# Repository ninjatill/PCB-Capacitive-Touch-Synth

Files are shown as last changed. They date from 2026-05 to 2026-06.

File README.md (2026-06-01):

# PCB-Capacitive-Touch-Synth
A Raspberry Pi-based synthesizer with capacitive touch keys directly on a PCB.

## Licensing

### Hardware
All files in `/hardware` are licensed under:

CC BY-NC-SA 4.0

### Firmware
All files in `/firmware` are licensed under:

GPLv3

## Concept
The PCB-Capacitive-Touch-Synth started as a sub-component of a larger science fair project. For my daughter's next science fair project (5th grade), she chose to create Plasma Speakers as we saw on the Franzoli Electronics YouTube page. The plasma speakers are flyback transformers that create a high-voltage arc (which ionizes the air into plasma). The frequeny of the arc creates audio tones. On Franzoli's demonstration videos, he plays MIDI-style music with each speaker acting as a left or right channel/voice. That is the concept we want to re-create.

If we re-create the plasma speakers, then how do we make then into an interactive display for the fair? Well, what if we had 2 midi-controller keyboards hooked up to a host PC. The host PC would do the heavy lifting of audio generation and output to the plasma speakers. Each keyboard would play its notes through either the left or right channel respectively. That's the main idea: 2 keyboards, a host PC, and plasma speakers.

To source the midi keyboards, you could go to Amazon and pick up a 30$-70$ keyboard (higher-end small midi keyboards can run upwards of 200-500$). But, commercial MIDI controllers usually do not output sound directly, it requires a host PC; so its usefullness outside the fair display is limited. The size and scale of the keyboards should be small (to match the entire setup which is portable and compact for a 36"-48" display.) The speakers on Franzoli's demos are very industrial/scientific looking. I thought commercial keyboards would look out of place or be too expensive. So I had a concept of creating keyboards printed on PCBs using capacitive touch buttons. The keyboards would be build to our specific needs and we can build in many features because of the DIY nature.

I decided the best course of action was to have my daughter re-create Fanzoli's Easy-Flyback circuits. It will teach her basic electrical components, schematic creation and PCB layout and fabrication. I think that's a wealth of knowledge for a 10 year old (maybe 11 by the time this comes to fruition). I will handle creating the PCB Capacitive Touch Synthesizer. It is a large complex project and is difficult for my own skill set.

## Documentation

- [Design Notes](docs/design-notes.md)

## Concept to Schematic
As an electrical engineer, I have created PCBs for simple devices. A capacitive touch synthesizer is the largest project/PCB I will have created. So, to jumpstart the project, I consulted my new "friend", ChatGPT. ChatGPT was able to answer questions and make recommendations faster than I could search DigiKey/Mouser, review datasheets, and find the right combination of ICs. But to be clear, I was driving the design. I wanted specific features and ChatGPT helped me realize those features faster than I could alone.

I started with the following design critera
- The front of the keyboard should be as flat as possible both for aestectic and functional reasons.
  - Aesthetically, I don't want a lot of clutter on the front of the board.
  - Functionally, Children will be interacting with this. I don't want exposed chip leads or solder pads. I also don't want through hole components sticking up with sharp edges. If kids can touch it, they will.
- The keyboard should be as small as possible but still allowing for decent usability (key widths wide enough for easy touch, etc.)
  
From the design criteria, we landed with some of the following choices:
- We will use capacitive touch sensors for the piano keys. Capacitive touch reduces mechanical parts that need fabricated (via 3D printing). It's more touch-friendly than many momentary push buttons.
- We will keep all IC's on the back of the board. Only LEDs and a volume knob will protrude from the front.
- We will use only surface mount components (to eliminate protrusions through the board and maintain the flat asthetic.)
- We will 3D print a back cover that serves 2 purposes: 
  - It will cover the back circuitry to prevent tampering.
  - It will raise the PCB off the display surface by a comfortable distance (and tilt it forward a few degrees) to increase usability.

## Basic Functionality
- The synthesizer will funtion in two main modes: standalone and MIDI.
  - In standalone mode, the keyboard will generate its own sounds via speaker or headphones.
  - In MIDI mode, the keyboard will send MIDI commands to a host PC (this is the intended mode for the science fair.

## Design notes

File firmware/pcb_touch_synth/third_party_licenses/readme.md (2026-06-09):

# Third-party licenses

This firmware is released under the **GNU General Public License v3.0** (see
`LICENSE` in the repository root). It incorporates the following third-party
components, each with their own license terms. Both are compatible with GPL v3.

---

## FatFS — Generic FAT Filesystem Module

- **Author:** ChaN
- **Source:** http://elm-chan.org/fsw/ff/
- **License:** FatFS License (BSD 1-clause style) — see `fatfs/license.txt`
- **Used by:** `audio/sample_loader.cpp` (via no-OS-FatFS-SD-SPI-RPi-Pico wrapper)
- **GPL v3 compatibility:** Compatible — permissive, no copyleft conditions

---

## no-OS-FatFS-SD-SPI-RPi-Pico

- **Author:** Carl John Kugler III
- **Source:** https://github.com/carlk3/no-OS-FatFS-SD-SPI-RPi-Pico
- **License:** Apache License 2.0 — see `no-os-fatfs-sd-spi-rpi-pico/license.txt`
- **Used by:** `audio/sample_loader.cpp`, `board/hw_config.c`
- **GPL v3 compatibility:** Compatible — the FSF explicitly states Apache 2.0 is
  compatible with GPL v3. See https://www.gnu.org/licenses/license-compatibility.html

---

## Raspberry Pi Pico SDK

- **Author:** Raspberry Pi Ltd
- **Source:** https://github.com/raspberrypi/pico-sdk
- **License:** BSD 3-Clause — included with the SDK distribution
- **Used by:** All firmware files
- **GPL v3 compatibility:** Compatible — permissive BSD licence

---

*These notices satisfy the attribution requirements of the Apache 2.0 and
FatFS licenses. The combined firmware as a whole is distributed under GPL v3.*

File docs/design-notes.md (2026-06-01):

# Design Notes

This document captures the reasoning behind major design choices in the PCB Capacitive Touch Synth project. The goal is to explain not only what was built, but why certain tradeoffs were made.

## Project Goals

- Standalone capacitive-touch musical keyboard/synth
- USB MIDI support for host-connected use
- Local audio output through speaker and/or headphones
- Compact PCB-first physical design
- Reasonably hand-assemblable prototype
- Open hardware and firmware structure

## Major Design Decisions

### PCB as the Primary Interface

The touch pads, labels, speaker grille, and user-facing controls are built directly into the PCB.

**Reasoning:**

- Reduces mechanical complexity
- Makes the PCB part of the finished product
- Supports capacitive touch pads directly on the board
- Keeps the enclosure simpler

**Tradeoffs:**

- PCB layout becomes more constrained
- Front-side aesthetics matter
- Routing must avoid touch-sensitive areas

---

### RP2040 Microcontroller

The project uses the RP2040 as the main controller.

**Reasoning:**

- Good GPIO count
- Strong USB support
- Low cost
- Good community/toolchain support
- PIO flexibility for future audio or protocol needs

**Tradeoffs:**

- No built-in DAC
- External flash required
- Some audio features require careful firmware design

---

### Capacitive Touch Input

Capacitive touch controllers are used instead of mechanical keys.

**Reasoning:**

- Keeps the top surface flat
- Reduces mechanical wear
- Supports a PCB-as-instrument design
- Allows flexible pad shapes and labels

**Tradeoffs:**

- Requires careful grounding and routing
- More sensitive to layout and environmental noise
- Firmware must handle calibration and false touches

---

### Local Audio Output

The board supports local audio through a small speaker and headphone output.

**Reasoning:**

- Allows standalone operation without a host computer
- Makes the instrument immediately usable
- Supports testing without external equipment

**Tradeoffs:**

- Audio layout requires more care
- Speaker volume and bass are limited by enclosure size
- Headphone/speaker switching adds schematic and layout complexity

---

### Separate Audio/Analog Ground Area

The audio section uses a more deliberate ground layout to reduce noise coupling.

**Reasoning:**

- Keeps noisy digital return currents away from sensitive audio paths
- Helps headphone and amplifier performance
- Makes the audio section easier to reason about during layout review

**Tradeoffs:**

- Ground regions must reconnect intentionally
- Poor stitching could make noise worse instead of better
- Requires review before fabrication

---

### GitHub Project Structure

The repository separates hardware and firmware.

```text
hardware/
firmware/
docs/
```

**Reasoning:**

- Keeps KiCad files separate from source code
- Allows hardware and firmware to evolve together
- Makes the project easier for others to navigate

**Tradeoffs:**

- Requires discipline around commits and documentation
- Generated fabrication outputs should be managed carefully

### Open Questions
- Final enclosure design
- Speaker chamber geometry
- Final firmware architecture
- USB MIDI/sample-transfer behavior
- Production versus prototype assembly choices

Revision Log
Date	Note
2026-05-19	Initial design notes document created

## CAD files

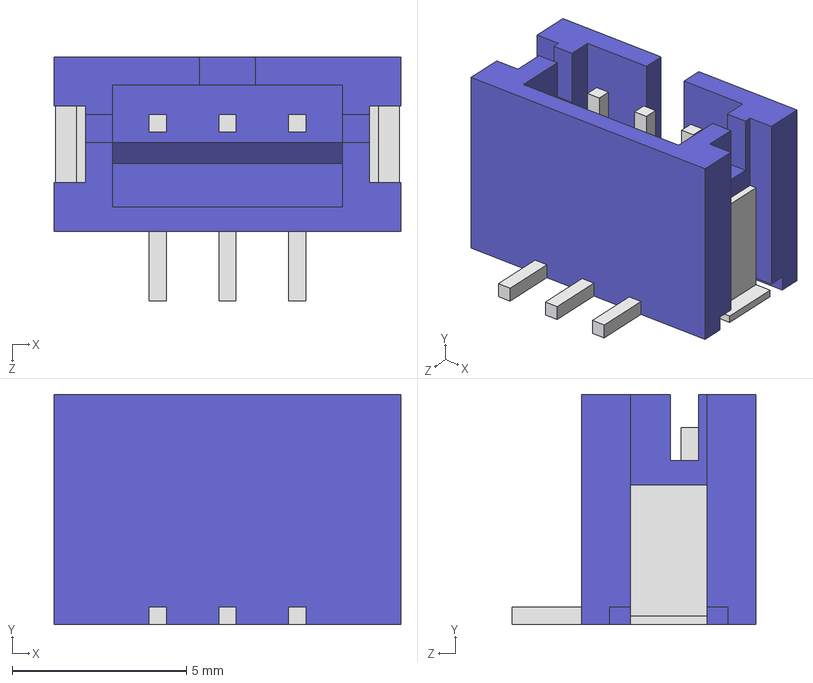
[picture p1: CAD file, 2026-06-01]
hardware/3dmodels/B3B-PH-SM4-TB.STEP
9.95 x 6.60 x 7.00 mm

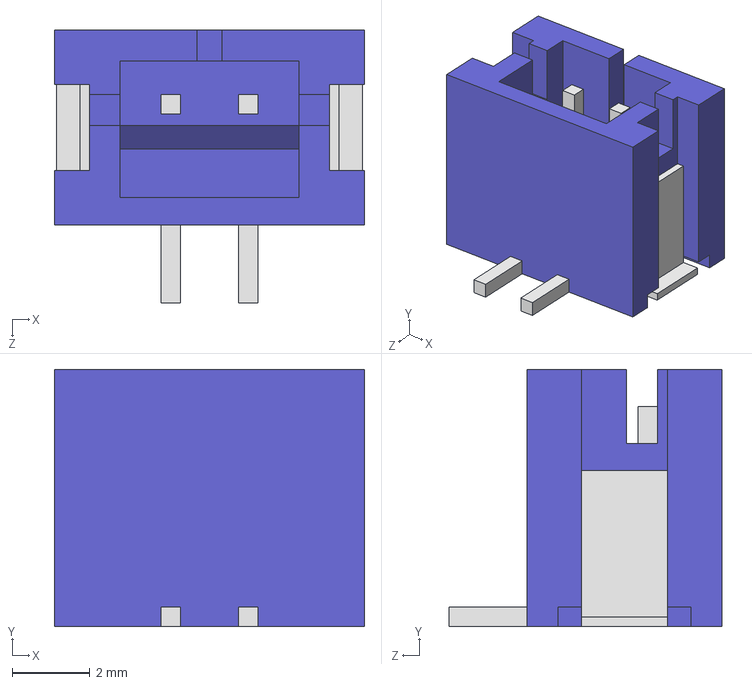
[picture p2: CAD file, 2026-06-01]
hardware/3dmodels/B2B-PH-SM4-TB.STEP
7.95 x 6.60 x 7.00 mm

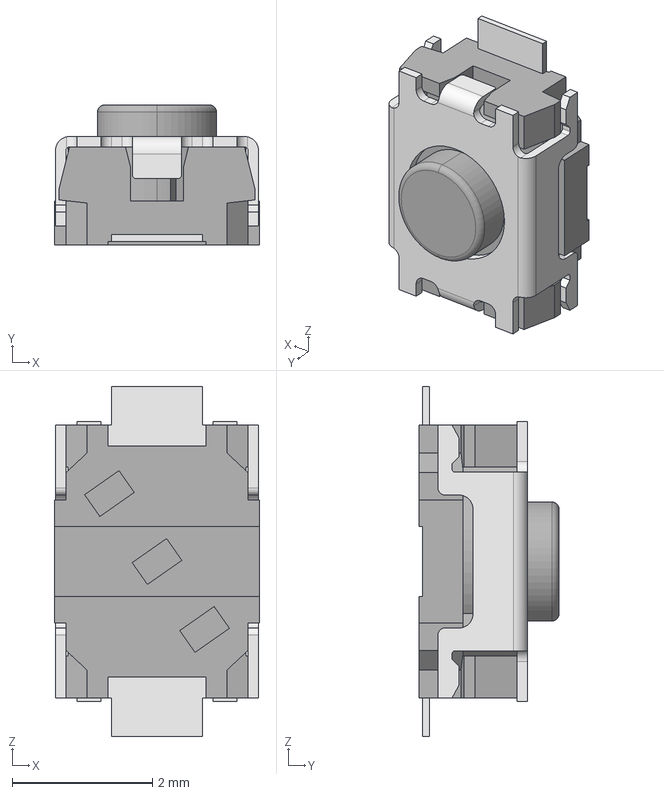
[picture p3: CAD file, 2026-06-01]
hardware/3dmodels/swt0110-020016ssa.stp
2.93 x 2.00 x 5.00 mm

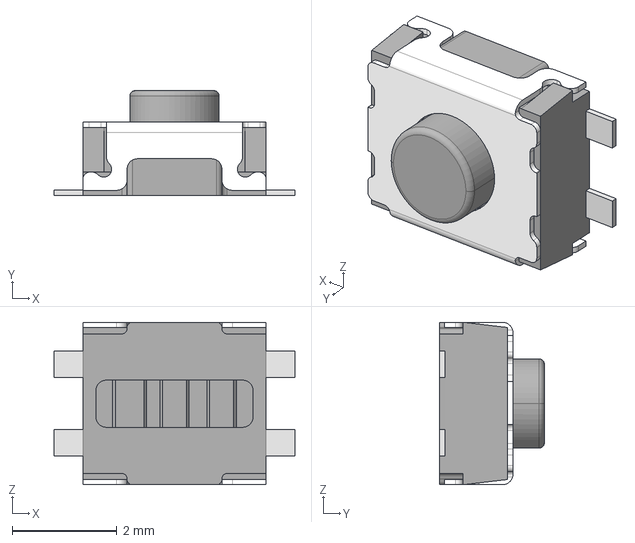
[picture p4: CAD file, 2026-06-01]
hardware/3dmodels/swt0115-020025ssa.stp
4.60 x 2.00 x 3.10 mm

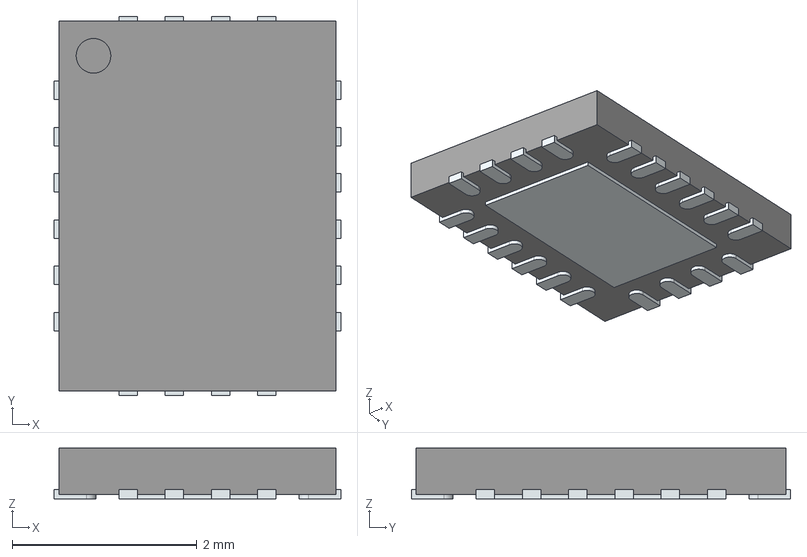
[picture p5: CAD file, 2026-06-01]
hardware/3dmodels/PI3USB9281CXWEX.stp
3.10 x 4.10 x 0.55 mm
ThermalPin
PinsArrayLR
PinsArrayTB

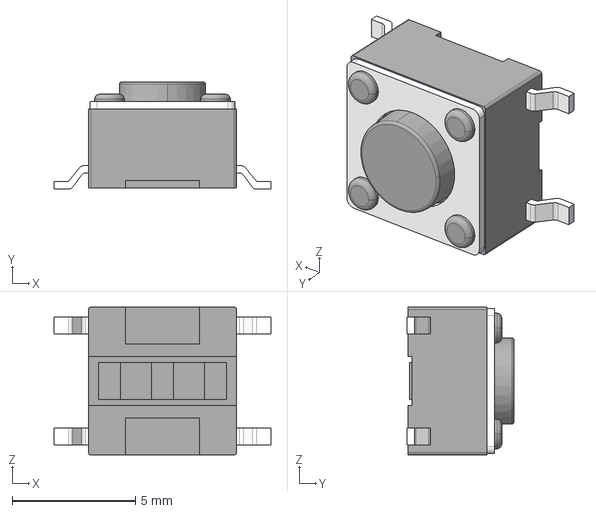
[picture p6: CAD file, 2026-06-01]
hardware/3dmodels/swt0310-043025gsa.stp
8.80 x 4.35 x 6.00 mm

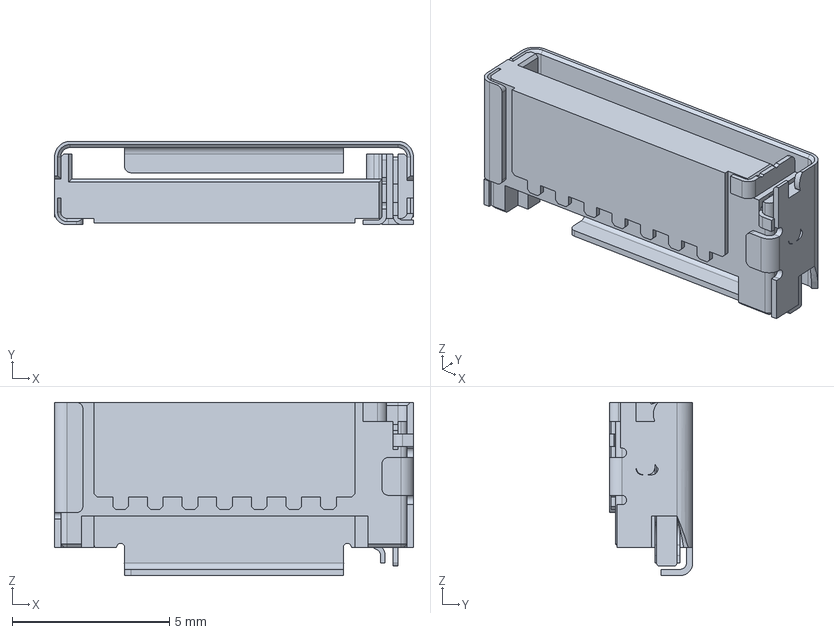
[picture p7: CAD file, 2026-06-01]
hardware/3dmodels/10067099-200lf.stp
11.4 x 2.65 x 5.50 mm

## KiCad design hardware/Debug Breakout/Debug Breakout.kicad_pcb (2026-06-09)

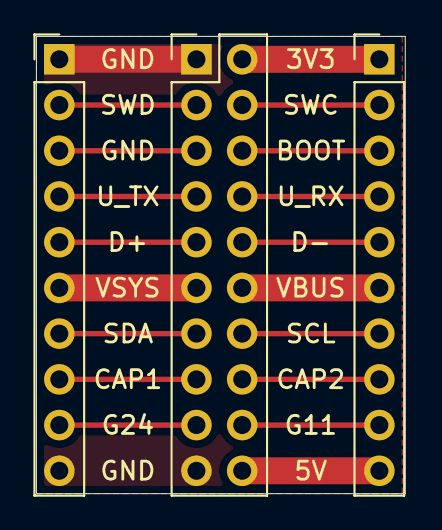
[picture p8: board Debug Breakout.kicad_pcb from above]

Board: 2 copper layers, 20.5 x 25.4 mm, 3 parts (0 on the bottom side), 19 nets.

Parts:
J1: PinHeader_2x10_P2.54mm_Vertical
J2, J3: Conn_01x10; PinHeader_1x10_P2.54mm_Vertical

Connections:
+3.3V: J1.2, J2.1
+5V: J1.20, J2.10
/BOOTSEL: J1.6, J2.3
/CAP1_GPIO: J1.15, J3.8
/CAP2_GPIO: J1.16, J2.8
/DEBUG_DM: J1.10, J2.5
/DEBUG_DP: J1.9, J3.5
/GPIO11: J1.18, J2.9
/GPIO24: J1.17, J3.9
/I2C1_SCL: J1.14, J2.7
/I2C1_SDA: J1.13, J3.7
/RUN: J1.5, J3.3
/SWCKL: J1.4, J2.2
/SWDIO: J1.3, J3.2
/UART1_RX: J1.8, J2.4
/UART1_TX: J1.7, J3.4
GND: J1.1, J1.19, J3.1, J3.10
VBUS: J1.12, J2.6
VSYS: J1.11, J3.6

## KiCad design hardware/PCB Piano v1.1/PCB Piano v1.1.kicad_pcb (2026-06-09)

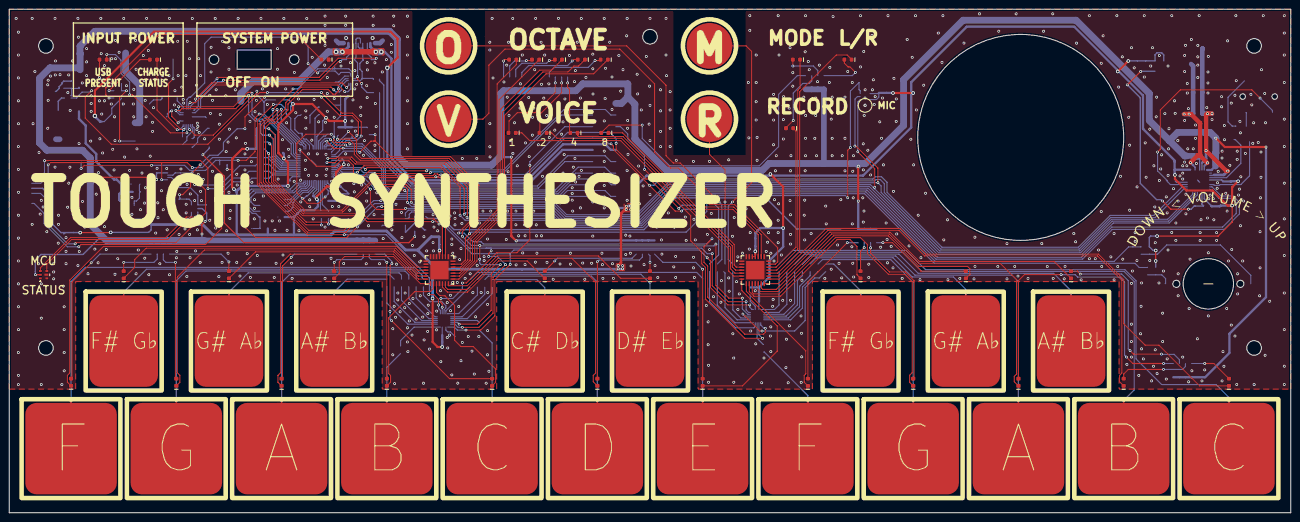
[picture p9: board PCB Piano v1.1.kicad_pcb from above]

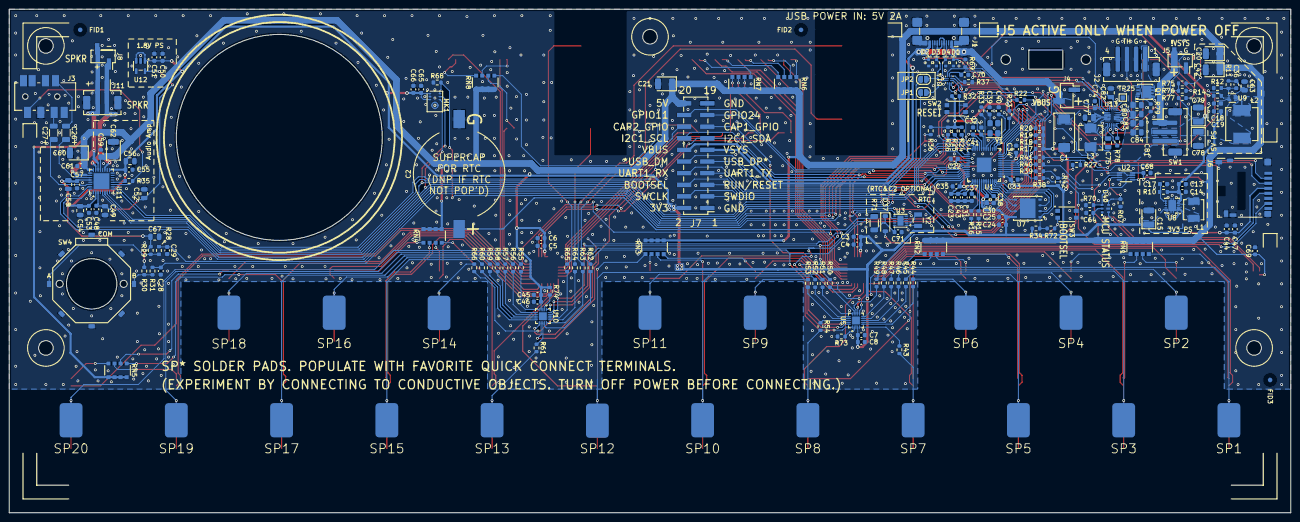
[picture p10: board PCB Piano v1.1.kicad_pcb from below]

Board: 2 copper layers, 280.0 x 110.0 mm, 284 parts (216 on the bottom side), 222 nets.

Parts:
C1: 47uF; CP_EIA-7343-43_Kemet-X
C2: 1F; SuperCap_HType_FoldedOutLegs
C3, C6, C8, C13, C18, C23, C24, C31, C37, C44, C45, C50, C66, C74: 1uF; C_0603_1608Metric
C4, C5, C7, C14, C17, C19, C22, C25, C28, C29, C30, C32, C33, C34, C35, C38, C41, C43, C46, C47, C48, C51, C53, C55, C57, C59, C61, C64, C65, C68, C69, C70, C71: .1uF; C_0603_1608Metric
C15, C20, C21, C42, C60, C62, C78, C79: 47uF; CP_EIA-3528-15_AVX-H
C26, C27: 100uF; C_1206_3216Metric
C36: 220pF; C_0603_1608Metric
C39, C40: 27pF; C_0603_1608Metric
C49, C52, C54, C56, C58, C63, C67, C77, C80, C81, C82, C83, C84: 10uF; C_0805_2012Metric
C75: 22nF; C_0805_2012Metric
D1, D2, D3, D4: ESD321; D_SOD-523
D5, D6, D7, D8, D9, D10, D11, D12, D13, D14, D15, D16, D17, D18, D19, D20, D21, D22, D23, D24, D25, D26, D27, D28, D29, D30, D31, D32, D33, D34, D35, D36, D43, D44, D45: 3.3fV 180mcd; LED_0603_1608Metric
D37: Schottky; D_SOD-123
D40, D41: Dotstar LED; APA102-2020
FID1, FID2, FID3: Fiducial; Fiducial_1mm_Mask3mm
H1, H2, H3, H4, H5: MountingHole; MountingHole_3.2mm_M3
J1: USB4110-GF-A; USB_C_Receptacle_GCT_USB4110
J2: JST PH 4-PIN; JST_PH_B4B-PH-SM4-TB_1x04-1MP_P2.00mm_Vertical
J3: 3.5mm TRRS; AudioJack_TRS_Switch_TR1R2S_SJ3-35024K-SMT-TR
J4, J5, J8: PinHeader 1x02 SMT; PinHeader_1x02_P2.54mm_Vertical_SMD_Pin1Right
J6: micro SD Card Slot; microSD_HC_Hirose_DM3D-SF
J7: PinHeader 2x10 SMT Odd_Even; PinHeader_2x10_P2.54mm_Vertical_SMD
J11: JST-PH 2-PIN SMT; JST_PH_B2B-PH-SM4-TB_1x02-1MP_P2.00mm_Vertical
JP1, JP2: SolderJumper_2_Open; SolderJumper-2_P1.3mm_Open_RoundedPad1.0x1.5mm
L1: 2.2uH; L_Bourns_SRP4020T_4.06x4.45x2.0mm
L2: 2.2uH; L_Pulse_BMRB00060630_7.3x6.6mm
L3: 1uH; L_Sumida_0530CDMCCDS-1R0MC_5.4x5.2mm
MK1: MEMS I2S Microphone; InvenSense_ICS-43432-7_4x3mm
Q1: P-Ch Power MOSFET; PPAK_3x3
R10: 100; R_0603_1608Metric
R11: 732k; R_0603_1608Metric
R12, R14, R25, R26, R27, R36, R37, R67, R69, R70, R73, R74, R79: 100k; R_0603_1608Metric
R15, R16, R38, R39, R40, R41: 27; R_0603_1608Metric
R17, R18, R19, R20: 4.7k; R_0603_1608Metric
R22, R23, R24, R28, R29, R30, R31, R32, R34, R42, R43, R44, R45, R46, R47, R48, R49, R50, R51, R52, R53, R54, R55, R56, R57, R58, R59, R60, R61, R62, R63, R64, R65, R66, R68, R78: 10k; R_0603_1608Metric
R33, R72: 1k; R_0603_1608Metric
R35: 2.2k; R_0603_1608Metric
R71: 150; R_1206_3216Metric
R75, R76, R77: 1.5k; R_0603_1608Metric
RN1, RN2, RN3, RN4, RN5, RN6, RN7, RN8: 180 Ohm; R_Array_Convex_4x1206
SP1, SP2, SP3, SP4, SP5, SP6, SP7, SP8, SP9, SP10, SP11, SP12, SP13, SP14, SP15, SP16, SP17, SP18, SP19, SP20: Pad_Solder_SMT_5x7mm
SW1: JST-PH 1x03 SMT; JST_PH_B3B-PH-SM4-TB_1x03-1MP_P2.00mm_Vertical
SW2, SW3: Pushbutton MO; SW_SWT0115-020025SSA_REVA
SW4: MER1045-24; Switch_RotaryEncoder_MER1045-24
SWCUT1: MFS 126 D; Switch_Slide_MFS126E_PanelCutout
TP1, TP3, TP5, TP7, TP8, TP10, TP12, TP13, TP15, TP17, TP19, TP20: Touchpad_WhiteKey
TP2, TP4, TP6, TP9, TP11, TP14, TP16, TP18: Touchpad_BlackKey
TP21, TP22, TP23, TP24: Touchpad_Circle_10mm
TP25: TestPoint_Square; TestPoint_Pad_1.0x1.0mm
U1: RP2040; QFN-56-1EP_7x7mm_P0.4mm_EP3.2x3.2mm
U2: Dual Line Buffer; VSSOP-8_2.3x2mm_P0.5mm
U3: RTC; DFN-10-1EP_2.6x2.6mm_P0.5mm_EP1.3x2.2mm
U4, U6: LED Controller; NXP_HVQFN-28_6mmx6mmx0.85mm
U5, U10: Touch Controller; VQFN-20-1EP_3x3mm_P0.4mm_EP1.7x1.7mm
U7: 128MBit; WSON-8-1EP_6x5mm_P1.27mm_EP3.4x4.3mm
U8: 3.3V; Texas_DRC0010J
U9: 5V; SOT-563
U11: Audio DAC Class-D I2S/I2C; Texas_RHB0032E_VQFN-32-1EP_5x5mm_P0.5mm_EP3.45x3.45mm
U12: 1.8V; SOT-23-5
U13: USB C Sink Ctrl/Batt Chgr; QFN-22_2.5x3.2mm_P0.4mm
U14: 1:2 USB MUX; TQFN-10_ZL_1.6x1.3mm_P0.4mm
Y1: 12MHz; Crystal_SMD_Abracon_ABM8G-4Pin_3.2x2.5mm
Y2: 32.768kHz; Crystal_Kyocera_DT32_3.2x1.5mm

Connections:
+1V1: C37.1, C38.1, C41.1, U1.23 (DVDD), U1.45 (VREG_VOUT), U1.50 (DVDD)
+1V8: C48.1, C49.1, C52.1, U11.3 (DVDD), U12.5 (OUT)
+3.3V: C3.1, C4.1, C5.1, C6.1, C7.1, C8.1, C15.1, C22.1, C23.1, C24.1, C25.1, C30.1, C31.1, C32.1, C33.1, C34.1, C35.1, C43.1, C44.1, C45.1, C46.1, C47.1, C50.1, C51.1, C53.1, C54.1, C55.1, C56.1, C57.1, C58.1, C65.1, C66.1, C67.1, J6.4 (VDD), J7.2, MK1.1 (LR), MK1.3 (VDD), R17.1, R18.1, R19.1, R20.1, R22.1, R23.1, R24.1, R25.1, R26.1, R27.1, R29.2, R30.2, R32.1, R34.1, R36.1, R42.1, R74.1, U1.1 (IOVDD), U1.10 (IOVDD), U1.22 (IOVDD), U1.33 (IOVDD), U1.42 (IOVDD), U1.43 (ADC_AVDD), U1.44 (VREG_VIN), U1.48 (USB_VDD), U1.49 (IOVDD), U4.25 (VDD), U5.4 (VDD), U6.25 (VDD), U6.26 (A0), U7.8 (VCC), U8.1 (VOUT), U8.10 (FB), U10.4 (VDD), U11.2 (IOVDD), U11.17 (AVDD), U11.28 (HPVDD), U12.1 (IN), U12.3 (EN)
+5V: C20.1, C21.1, C36.1, C42.1, C59.1, C60.1, C61.1, C62.1, C63.1, C64.1, C68.1, C69.1, D40.2 (VDD), D41.2 (VDD), J7.20, R11.1, RN1.5 (R4.2), RN1.6 (R3.2), RN1.7 (R2.2), RN1.8 (R1.2), RN2.5 (R4.2), RN2.6 (R3.2), RN2.7 (R2.2), RN2.8 (R1.2), RN3.5 (R4.2), RN3.6 (R3.2), RN3.7 (R2.2), RN3.8 (R1.2), RN4.5 (R4.2), RN4.6 (R3.2), RN4.7 (R2.2), RN4.8 (R1.2), RN5.5 (R4.2), RN5.6 (R3.2), RN5.7 (R2.2), RN5.8 (R1.2), RN6.5 (R4.2), RN6.6 (R3.2), RN6.7 (R2.2), RN6.8 (R1.2), RN7.5 (R4.2), RN7.6 (R3.2), RN7.7 (R2.2), RN7.8 (R1.2), RN8.5 (R4.2), RN8.6 (R3.2), RN8.7 (R2.2), RN8.8 (R1.2), U2.8 (VCC), U9.6 (VOUT), U11.21 (SPKVDD), U11.24 (SPKVDD)
/LED/I2C1_SCL: J7.14, R20.2, U1.9 (GPIO7), U3.7 (SCL), U4.23 (SCL), U6.23 (SCL), U11.10 (SCL), U13.16 (SCL)
/LED/I2C1_SDA: J7.13, R19.2, U1.8 (GPIO6), U3.6 (SDA), U4.24 (SDA), U6.24 (SDA), U11.9 (SDA), U13.15 (SDA)
/LED/LED_100: D5.1 (K), U4.3 (LED0)
/LED/LED_101: D6.1 (K), U4.4 (LED1)
/LED/LED_102: D7.1 (K), U4.5 (LED2)
/LED/LED_103: D8.1 (K), U4.6 (LED3)
/LED/LED_104: D9.1 (K), U4.7 (LED4)
/LED/LED_105: D10.1 (K), U4.8 (LED5)
/LED/LED_106: D11.1 (K), U4.9 (LED6)
/LED/LED_107: D12.1 (K), U4.10 (LED7)
/LED/LED_108: D13.1 (K), U4.12 (LED8)
/LED/LED_109: D14.1 (K), U4.13 (LED9)
/LED/LED_110: D15.1 (K), U4.14 (LED10)
/LED/LED_111: D29.1 (K), U4.15 (LED11)
/LED/LED_112: D28.1 (K), U4.16 (LED12)
/LED/LED_113: D27.1 (K), U4.17 (LED13)
/LED/LED_114: D26.1 (K), U4.18 (LED14)
/LED/LED_115: D25.1 (K), U4.19 (LED15)
/LED/LED_200: D30.1 (K), U6.3 (LED0)
/LED/LED_201: D31.1 (K), U6.4 (LED1)
/LED/LED_202: D32.1 (K), U6.5 (LED2)
/LED/LED_203: D33.1 (K), U6.6 (LED3)
/LED/LED_204: D16.1 (K), U6.7 (LED4)
/LED/LED_205: D17.1 (K), U6.8 (LED5)
/LED/LED_206: D18.1 (K), U6.9 (LED6)
/LED/LED_207: D19.1 (K), U6.10 (LED7)
/LED/LED_208: D20.1 (K), U6.12 (LED8)
/LED/LED_209: D21.1 (K), U6.13 (LED9)
/LED/LED_210: D22.1 (K), U6.14 (LED10)
/LED/LED_211: D23.1 (K), U6.15 (LED11)
/LED/LED_212: D24.1 (K), U6.16 (LED12)
/LED/LED_213: D36.1 (K), U6.17 (LED13)
/LED/LED_214: D35.1 (K), U6.18 (LED14)
/LED/LED_215: D34.1 (K), U6.19 (LED15)
/LED/LED_~EN: R36.2, U1.31 (GPIO20), U4.20 (~OE), U6.20 (~OE)
/MCU/5V_EN: R14.2, U1.30 (GPIO19), U9.2 (EN)
/MCU/AMP_INT: U1.41 (GPIO29/ADC3), U11.32 (GPIO1)
/MCU/AMP_~RST: U1.37 (GPIO25), U11.31 (~RESET)
/MCU/BOOTSEL: J7.6, R72.2, SW3.3
/MCU/CAP1_~INT: R23.2, U1.18 (GPIO15), U5.11 (*INT)
/MCU/CAP2_~INT: R24.2, U1.27 (GPIO16), U10.11 (*INT)
/MCU/CAPx_~RST: R25.2, U1.28 (GPIO17), U5.19 (*RESET), U10.19 (*RESET)
/MCU/CHG_~INT: R22.2, U1.12 (GPIO9), U13.8 (~INT)
/MCU/DS_~EN: R26.2, U1.29 (GPIO18), U2.1, U2.7
/MCU/ENC_A: C29.1, R28.2, U1.32 (GPIO21)
/MCU/ENC_B: C28.1, R31.1, U1.34 (GPIO22)
/MCU/GPIO11: J7.18, U1.14 (GPIO11)
/MCU/GPIO24: J7.17, U1.36 (GPIO24)
/MCU/I2C0_SCL: R18.2, U1.7 (GPIO5), U5.1 (SCL), U10.1 (SCL)
/MCU/I2C0_SDA: R17.2, U1.6 (GPIO4), U5.20 (SDA), U10.20 (SDA)
/MCU/I2S_BCLK: MK1.6 (SCK), U1.38 (GPIO26/ADC0), U11.7 (BCLK)
/MCU/I2S_LRCLK: MK1.5 (WS), U1.39 (GPIO27/ADC1), U11.6 (WCLK)
/MCU/I2S_SDATA: U1.40 (GPIO28/ADC2), U11.5 (DIN)
/MCU/I2S_SDATA_MIC: MK1.7 (SD), R68.2, U1.35 (GPIO23)
/MCU/MCU_DM: R15.2, U14.6 (D-)
/MCU/MCU_DP: R16.2, U14.7 (D+)
/MCU/RTC_BATT: C2.1, R71.1
/MCU/RTC_VDD: C71.1, D37.1 (K), R71.2, U3.10 (VDD)
/MCU/RUN: J7.5, R32.2, SW2.3, U1.26 (RUN)
/MCU/SD_DET: J6.10 (DET_A), R27.2, U1.11 (GPIO8)
/MCU/SPI0_MISO: J6.7 (DAT0), R38.1
/MCU/SPI0_MOSI: J6.3 (CMD), R41.1, U2.5
/MCU/SPI0_SCK: J6.5 (CLK), R40.1, U2.2
/MCU/SPI0_~CS: J6.2 (DAT3/CD), R39.1, R42.2
/MCU/SWCLK: J7.4, U1.24 (SWCLK)
/MCU/SWDIO: J7.3, U1.25 (SWDIO)
/MCU/UART1_RX: J7.8, U1.16 (GPIO13)
/MCU/UART1_TX: J7.7, U1.15 (GPIO12)
/MCU/USB_SEL: R69.1, U1.13 (GPIO10), U14.10 (SEL)
/audio/HP_L: C26.1, U11.27 (HPL)
/audio/HP_R: C27.1, U11.30 (HPR)
/audio/SPKM: J8.1, J11.1, U11.19 (SPKM), U11.23 (SPKM)
/audio/SPKP: J8.2, J11.2, U11.22 (SPKP), U11.26 (SPKP)
/debug/CAP1_GPIO: J7.15, U5.12 (GPIO12)
/debug/CAP2_GPIO: J7.16, U10.12 (GPIO12)
/debug/DEBUG_DM: J7.10, JP2.1 (A)
/debug/DEBUG_DP: J7.9, JP1.1 (A)
/power/USB_CC1: D1.1 (K), J1.A5 (CC1), U13.1 (CC1)
/power/USB_CC2: D2.1 (K), J1.B5 (CC2), U13.22 (CC2)
/power/USB_DM: D3.1 (K), J1.A6 (D+), J1.B6 (D+), JP2.2 (B), U14.2 (Y-)
/power/USB_DP: D4.1 (K), J1.A7 (D-), J1.B7 (D-), JP1.2 (B), U14.1 (Y+)
/power/battery charger 2/BATT_POS: J2.1, Q1.D
/power/battery charger 2/CHG_BATT: C80.1, C81.1, Q1.S, U13.12 (BATTSNS), U13.14 (BATT)
/power/battery charger 2/CHG_DM: U13.20 (D-), U14.4 (M-)
/power/battery charger 2/CHG_DP: U13.21 (D+), U14.5 (M+)
/power/battery charger 2/CHG_OUT: C83.1, C84.1, D37.2 (A), L3.1, R75.1, R76.1, SW1.3 (C), U13.13 (SYS)
/power/battery charger 2/CHG_VCC: C70.1, C82.1, U13.19 (VCC), U14.9 (VDD)
/power/battery charger 2/TH1_POS: J2.3, R78.2, U13.10 (NTC1)
/touch/TOUCH_100: R43.2, SP7.1 (1_1), TP7.1
/touch/TOUCH_101: R44.2, SP6.1 (1_1), TP6.1
/touch/TOUCH_102: R45.2, SP5.1 (1_1), TP5.1
/touch/TOUCH_103: R46.2, SP4.1 (1_1), TP4.1
/touch/TOUCH_104: R47.2, SP3.1 (1_1), TP3.1
/touch/TOUCH_105: R48.2, SP2.1 (1_1), TP2.1
/touch/TOUCH_106: R49.2, SP1.1 (1_1), TP1.1
/touch/TOUCH_107: R50.2, SP12.1 (1_1), TP12.1
/touch/TOUCH_108: R51.2, SP11.1 (1_1), TP11.1
/touch/TOUCH_109: R52.2, SP10.1 (1_1), TP10.1
/touch/TOUCH_110: R53.2, SP9.1 (1_1), TP9.1
/touch/TOUCH_111: R54.2, SP8.1 (1_1), TP8.1
/touch/TOUCH_200: R55.2, SP20.1 (1_1), TP20.1
/touch/TOUCH_201: R56.2, SP19.1 (1_1), TP19.1
/touch/TOUCH_202: R57.2, SP18.1 (1_1), TP18.1
/touch/TOUCH_203: R58.2, SP17.1 (1_1), TP17.1
/touch/TOUCH_204: R59.2, SP16.1 (1_1), TP16.1
/touch/TOUCH_205: R60.2, SP15.1 (1_1), TP15.1
/touch/TOUCH_206: R61.2, SP13.1 (1_1), TP13.1
/touch/TOUCH_207: R62.2, TP22.1
/touch/TOUCH_208: R63.2, TP21.1
/touch/TOUCH_209: R64.2, TP24.1
/touch/TOUCH_210: R65.2, TP23.1
/touch/TOUCH_211: R66.2, SP14.1 (1_1), TP14.1
GND: C1.2, C2.2, C3.2, C4.2, C5.2, C6.2, C7.2, C8.2, C13.2, C14.2, C15.2, C17.2, C18.2, C19.2, C20.2, C21.2, C22.2, C23.2, C24.2, C25.2, C28.2, C29.2, C30.2, C31.2, C32.2, C33.2, C34.2, C35.2, C37.2, C38.2, C39.2, C40.2, C41.2, C42.2, C43.2, C44.2, C45.2, C46.2, C47.2, C48.2, C49.2, C50.2, C51.2, C52.2, C53.2, C54.2, C55.2, C56.2, C57.2, C58.2, C59.2, C60.2, C61.2, C62.2, C63.2, C64.2, C65.2, C66.2, C67.2, C68.2, C69.2, C70.2, C71.2, C74.2, C77.2, C78.2, C79.2, C80.2, C81.2, C82.2, C83.2, C84.2, D1.2 (A), D2.2 (A), D3.2 (A), D4.2 (A), D40.5 (GND), D41.5 (GND), D45.1 (K), J1.A1 (GND), J1.A12 (GND), J1.B1 (GND), J1.B12 (GND), J1.SH (SHIELD), J2.2, J2.4, J2.MP (MountPin), J3.2 (R2), J4.1, J5.1, J6.6 (VSS), J6.9 (DET_B), J6.SH (SHIELD), J7.1, J7.19, J11.MP (MountPin), MK1.2 (CONFIG), MK1.4 (GND), R12.1, R14.1, R37.1, R67.2, R68.1, R69.2, R70.2, R73.2, R79.2, SW1.MP, SW2.1, SW2.2, SW3.1, SW3.2, SW4.C, SW4.GND (MountPoints), U1.19 (TESTEN), U1.57 (GND), U2.4 (GND), U3.3 (CLKOE), U3.5 (VSS), U3.11 (EP), U4.1 (A3), U4.2 (A4), U4.11 (VSS), U4.21 (A5), U4.22 (EXTCLK), U4.26 (A0), U4.27 (A1), U4.28 (A2), U4.29 (VSS), U5.3 (GND), U5.21 (EP), U6.1 (A3), U6.2 (A4), U6.11 (VSS), U6.21 (A5), U6.22 (EXTCLK), U6.27 (A1), U6.28 (A2), U6.29 (VSS), U7.4 (GND), U7.9 (EP), U8.3 (PGND), U8.9 (GND), U8.11 (PGND), U9.4 (GND), U10.3 (GND), U10.21 (EP), U11.1 (IOVSS), U11.16 (AVSS), U11.18 (DVSS), U11.20 (SPKVSS), U11.25 (SPKVSS), U11.29 (HPVSS), U11.33 (EP), U12.2 (GND), U13.5 (PGND), U13.18 (AGND), U14.3 (GND), Y1.2 (G), Y1.4 (G)
unnamed: C39.1, R33.1, Y1.3
unnamed: D5.2 (A), RN1.4 (R4.1)
unnamed: D6.2 (A), RN1.3 (R3.1)
unnamed: D7.2 (A), RN1.2 (R2.1)
unnamed: D8.2 (A), RN1.1 (R1.1)
unnamed: D9.2 (A), RN2.4 (R4.1)
unnamed: D10.2 (A), RN2.3 (R3.1)
unnamed: D11.2 (A), RN2.2 (R2.1)
unnamed: D12.2 (A), RN2.1 (R1.1)
unnamed: D13.2 (A), RN3.4 (R4.1)
unnamed: D14.2 (A), RN3.3 (R3.1)
unnamed: D15.2 (A), RN3.2 (R2.1)
unnamed: D16.2 (A), RN3.1 (R1.1)
unnamed: D17.2 (A), RN4.4 (R4.1)
unnamed: D18.2 (A), RN4.3 (R3.1)
unnamed: D19.2 (A), RN4.2 (R2.1)
unnamed: D20.2 (A), RN4.1 (R1.1)
unnamed: D21.2 (A), RN5.1 (R1.1)
unnamed: D22.2 (A), RN5.2 (R2.1)
unnamed: D23.2 (A), RN5.3 (R3.1)
unnamed: D24.2 (A), RN5.4 (R4.1)
unnamed: D25.2 (A), RN6.1 (R1.1)
unnamed: D26.2 (A), RN6.2 (R2.1)
unnamed: D27.2 (A), RN6.3 (R3.1)
unnamed: D28.2 (A), RN6.4 (R4.1)
unnamed: D29.2 (A), RN7.1 (R1.1)
unnamed: D30.2 (A), RN8.1 (R1.1)
unnamed: D31.2 (A), RN7.4 (R4.1)
unnamed: D32.2 (A), RN7.3 (R3.1)
unnamed: D33.2 (A), RN7.2 (R2.1)
unnamed: D34.2 (A), RN8.2 (R2.1)
unnamed: D35.2 (A), RN8.3 (R3.1)
unnamed: D36.2 (A), RN8.4 (R4.1)
unnamed: D40.3 (CKI), R70.1, U2.6
unnamed: D40.1 (CKO), D41.3 (CKI)
unnamed: D40.6 (SDI), R67.1, U2.3
unnamed: D40.4 (SDO), D41.6 (SDI)
unnamed: D43.2 (A), R75.2
unnamed: D43.1 (K), U13.9 (PG/NTC2)
unnamed: D44.2 (A), R76.2
unnamed: D44.1 (K), U13.11 (STAT/IB)
unnamed: D45.2 (A), R77.2
unnamed: C27.2, J3.3 (R1)
unnamed: J3.1 (S), R35.2, U11.11 (VOL/MICDET)
unnamed: C26.2, J3.8 (T)
unnamed: J5.2, SW1.1 (A)
unnamed: Q1.G, R79.1
unnamed: R28.1, R29.1, SW4.A
unnamed: R30.1, R31.2, SW4.B
unnamed: R38.2, U1.2 (GPIO0)
unnamed: R39.2, U1.3 (GPIO1)
unnamed: R40.2, U1.4 (GPIO2)
unnamed: R41.2, U1.5 (GPIO3)
unnamed: U1.52 (QSPI_SCLK), U7.6 (CLK)
unnamed: U1.53 (QSPI_SD0), U7.5 (DI/IO_{0})
unnamed: U1.55 (QSPI_SD1), U7.2 (DO/IO_{1})
unnamed: U1.54 (QSPI_SD2), U7.3 (~WP/IO_{2})
unnamed: U1.51 (QSPI_SD3), U7.7 (~HOLD/~RESET/IO_{3})
unnamed: R16.1, U1.46 (USB_DM)
unnamed: R15.1, U1.47 (USB_DP)
unnamed: C40.1, U1.20 (XIN), Y1.1
unnamed: R33.2, U1.21 (XOUT)
unnamed: R34.2, R72.1, U1.56 (~QSPI_SS), U7.1 (~CS)
unnamed: U3.1 (OSCI), Y2.2
unnamed: U3.2 (OSCO), Y2.1
unnamed: R73.1, U5.2 (ADD_SEL)
unnamed: R43.1, U5.5 (BUTTON0)
unnamed: R44.1, U5.6 (BUTTON1)
unnamed: R45.1, U5.7 (BUTTON2)
unnamed: R46.1, U5.8 (BUTTON3)
unnamed: R47.1, U5.9 (BUTTON4)
unnamed: R48.1, U5.10 (BUTTON5)
unnamed: R49.1, U5.13 (BUTTON6)
unnamed: R50.1, U5.14 (BUTTON7)
unnamed: R51.1, U5.15 (BUTTON8)
unnamed: R52.1, U5.16 (BUTTON9)
unnamed: R53.1, U5.17 (BUTTON10)
unnamed: R54.1, U5.18 (BUTTON11)
unnamed: C17.1, R10.2, U8.6 (EN), U8.7 (PS/SYNC), U8.8 (VINA)
unnamed: L1.1, U8.4 (L1)
unnamed: L1.2, U8.2 (L2)
unnamed: C36.2, R11.2, R12.2, U9.1 (FB)
unnamed: L2.1, U9.5 (SW)
unnamed: R74.2, U10.2 (ADD_SEL)
unnamed: R55.1, U10.5 (BUTTON0)
unnamed: R56.1, U10.6 (BUTTON1)
unnamed: R57.1, U10.7 (BUTTON2)
unnamed: R58.1, U10.8 (BUTTON3)
unnamed: R59.1, U10.9 (BUTTON4)
unnamed: R60.1, U10.10 (BUTTON5)
unnamed: R61.1, U10.13 (BUTTON6)
unnamed: R62.1, U10.14 (BUTTON7)
unnamed: R63.1, U10.15 (BUTTON8)
unnamed: R64.1, U10.16 (BUTTON9)
unnamed: R65.1, U10.17 (BUTTON10)
unnamed: R66.1, U10.18 (BUTTON11)
unnamed: R35.1, U11.12 (MICBIAS)
unnamed: R78.1, U13.7 (VRNTC)
unnamed: TP25.1 (1_1), U13.17 (~RST)
unnamed: C75.1, U13.6 (BST)
unnamed: C77.1, U13.3 (PMID)
unnamed: C75.2, L3.2, U13.4 (SW)
unnamed: R37.2, U14.8 (~OE)
VBUS: C1.1, C74.1, J1.A4 (VBUS), J1.A9 (VBUS), J1.B4 (VBUS), J1.B9 (VBUS), J4.2, J7.12, U13.2 (IN)
VSYS: C13.1, C14.1, C18.1, C19.1, C78.1, C79.1, J7.11, L2.2, R10.1, R77.1, SW1.2 (B), U8.5 (VIN), U9.3 (VIN)

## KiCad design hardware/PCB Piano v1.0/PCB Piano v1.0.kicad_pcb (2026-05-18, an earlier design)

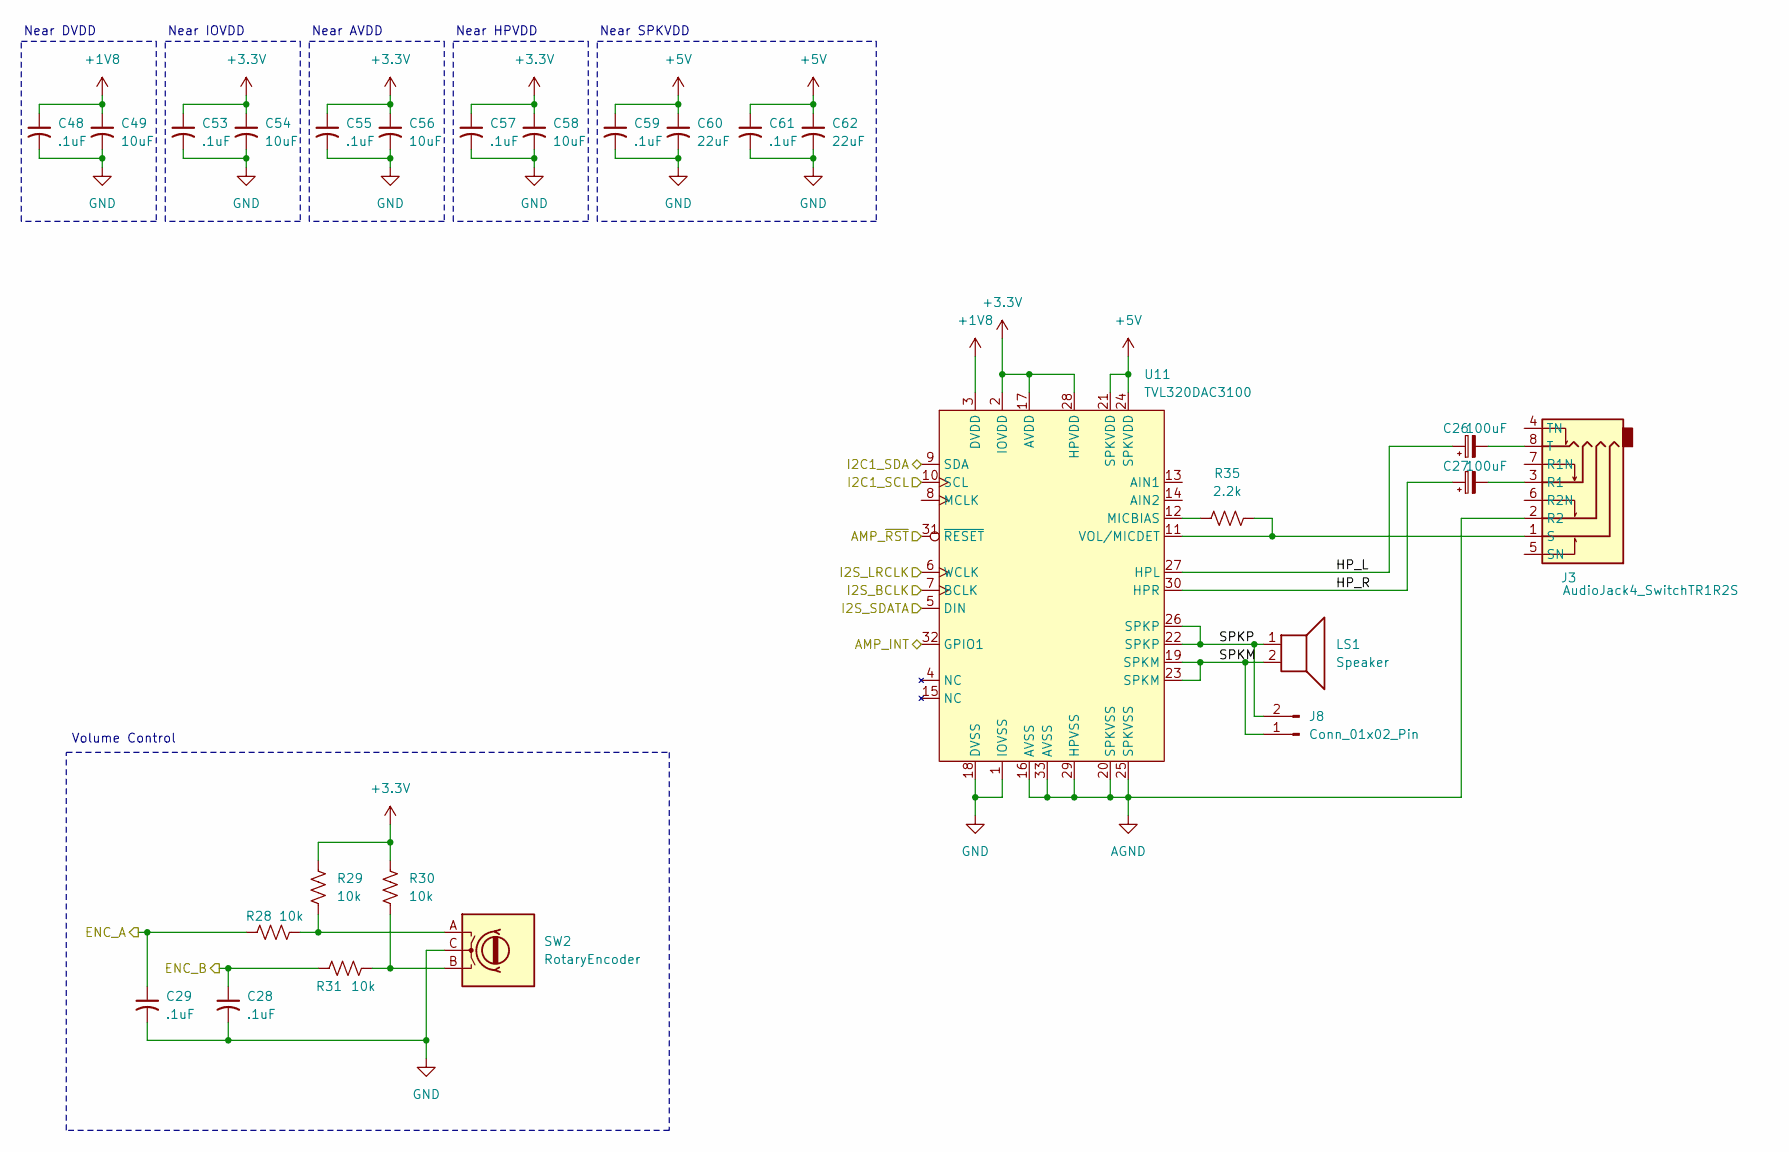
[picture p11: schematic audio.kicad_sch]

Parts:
C26, C27: 100uF; C_1206_3216Metric
C28, C29, C48, C53, C55, C57, C59, C61: .1uF; C_0603_1608Metric
C49, C54, C56, C58: 10uF; C_0603_1608Metric
C60, C62: 22uF; CP_EIA-6032-20_AVX-F
J3: AudioJack4_SwitchTR1R2S; AudioJack_TRS_Switch_TR1R2S_SJ3-35024K-SMT-TR
J8: Conn_01x02_Pin; JST_SH_BM03B-SRSS-TB_1x03-1MP_P1.00mm_Vertical
LS1: Speaker; TestPoint_2Pads_2.5mmx2.5mm_5mmSpacing
R28, R29, R30, R31: 10k; R_0603_1608Metric
R35: 2.2k; R_0603_1608Metric
SW2: RotaryEncoder; Switch_RotaryEncoder_MER1045-24
U11: TVL320DAC3100; Texas_RHB0032E_VQFN-32-1EP_5x5mm_P0.5mm_EP3.45x3.45mm

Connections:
+1V8: C48.1, C49.1, U11.3 (DVDD); also elsewhere on the board
+3.3V: C53.1, C54.1, C55.1, C56.1, C57.1, C58.1, R29.2, R30.2, U11.2 (IOVDD), U11.17 (AVDD), U11.28 (HPVDD); also elsewhere on the board
/LED/I2C1_SCL: U11.10 (SCL); also elsewhere on the board
/LED/I2C1_SDA: U11.9 (SDA); also elsewhere on the board
/MCU/AMP_INT: U11.32 (GPIO1); also elsewhere on the board
/MCU/AMP_~RST: U11.31 (~RESET); also elsewhere on the board
/MCU/ENC_A: C29.1, R28.2; also elsewhere on the board
/MCU/ENC_B: C28.1, R31.1; also elsewhere on the board
/MCU/I2S_BCLK: U11.7 (BCLK); also elsewhere on the board
/MCU/I2S_LRCLK: U11.6 (WCLK); also elsewhere on the board
/MCU/I2S_SDATA: U11.5 (DIN); also elsewhere on the board
/audio/SPKM: J8.1, LS1.2, U11.19 (SPKM), U11.23 (SPKM)
/audio/SPKP: J8.2, LS1.1, U11.22 (SPKP), U11.26 (SPKP)
AGND: J3.2 (R2), U11.16 (AVSS), U11.20 (SPKVSS), U11.25 (SPKVSS), U11.29 (HPVSS), U11.33 (AVSS)
unnamed: J3.1 (S), R35.2, U11.11 (VOL/MICDET)
unnamed: R28.1, R29.1, SW2.A
unnamed: R30.1, R31.2, SW2.B
unnamed: R35.1, U11.12 (MICBIAS)

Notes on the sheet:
Near SPKVDD
Near AVDD
Near IOVDD
Volume Control
Near DVDD
Near HPVDD

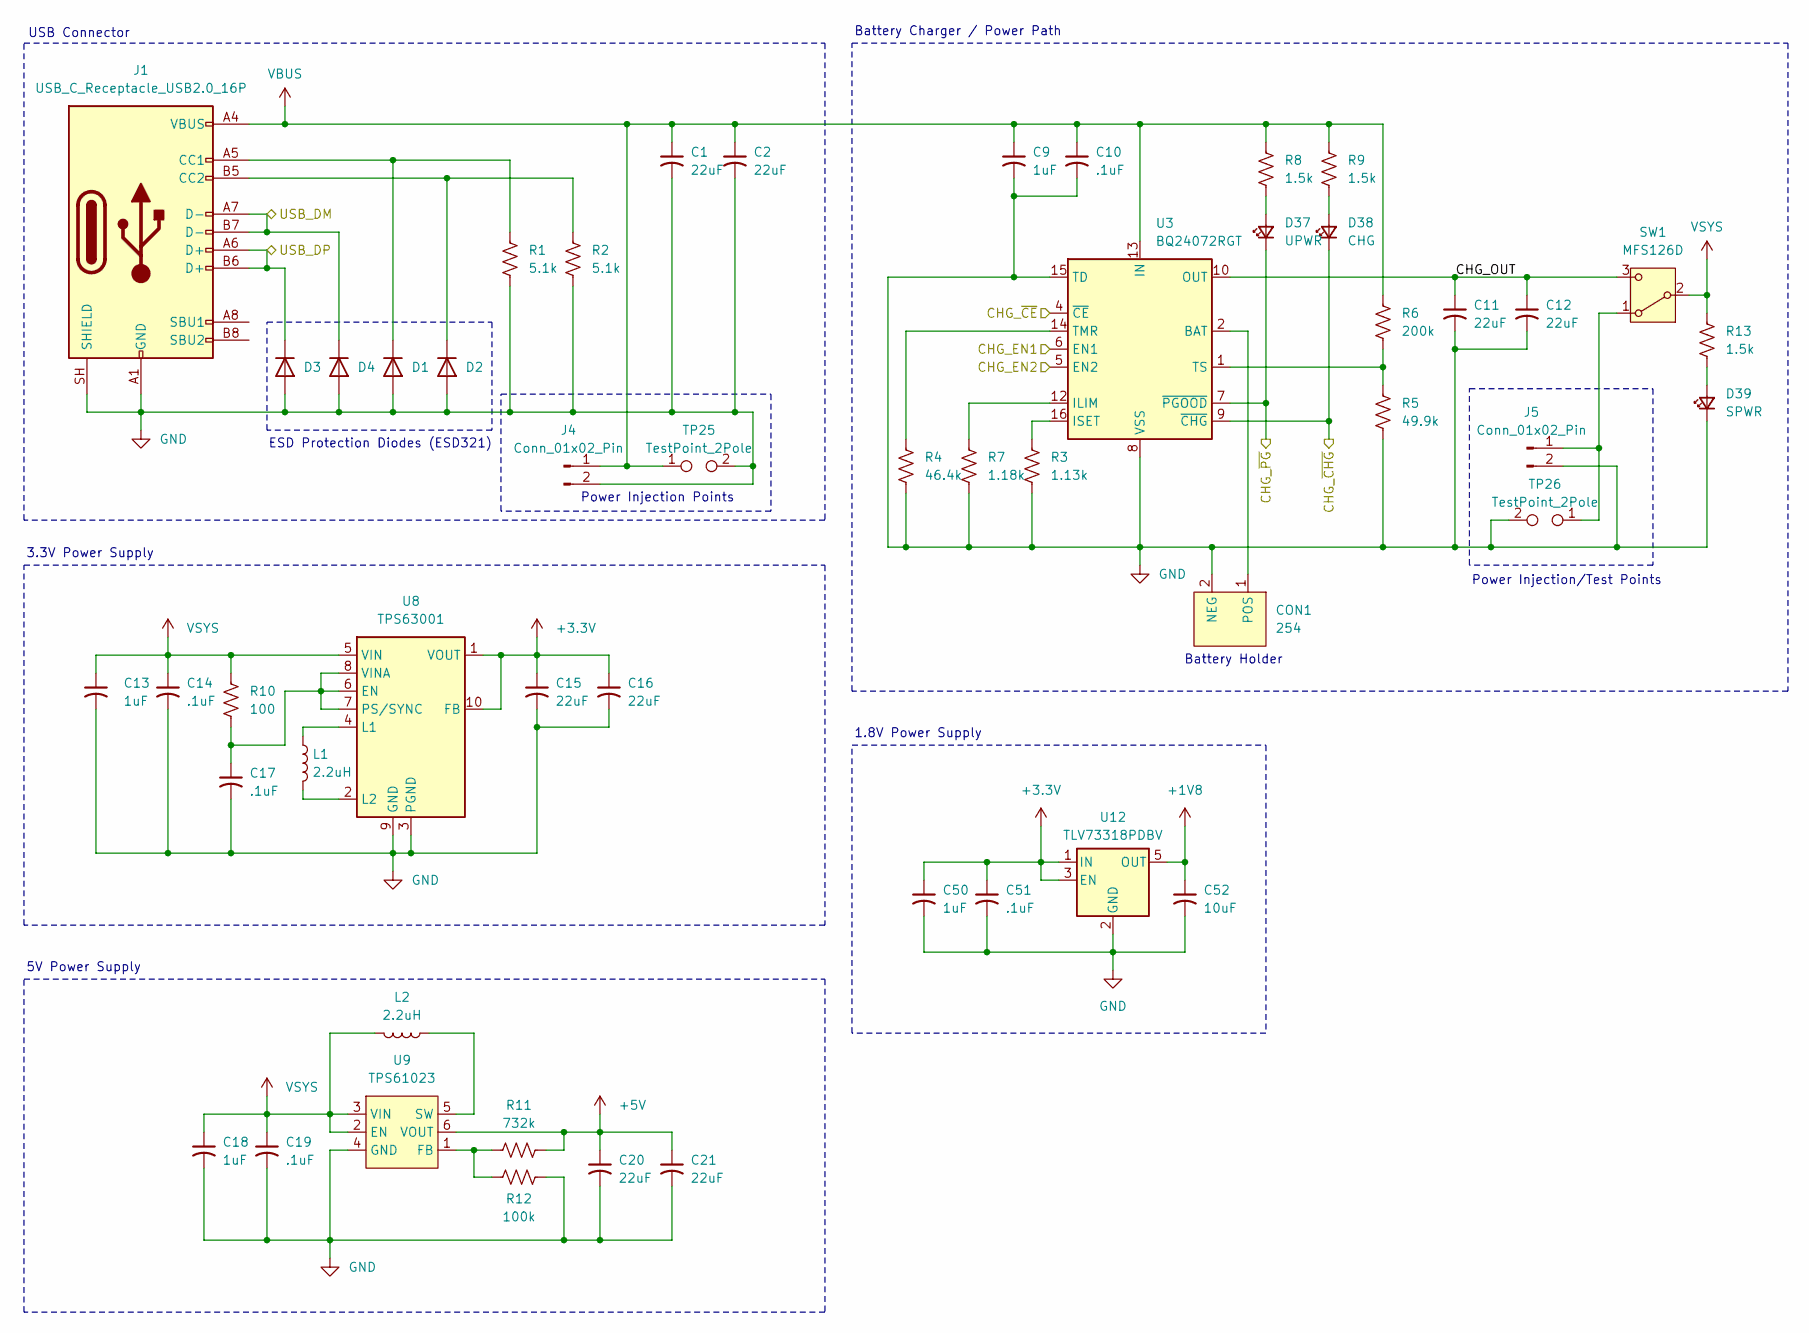
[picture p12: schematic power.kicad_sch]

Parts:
C1, C2, C11, C12, C15, C16, C20, C21: 22uF; CP_EIA-6032-20_AVX-F
C9, C13, C18, C50: 1uF; C_0603_1608Metric
C10, C14, C17, C19, C51: .1uF; C_0603_1608Metric
C52: 10uF; C_0603_1608Metric
CON1: 254; BatteryHolder_254Clips_18650Battery
D1, D2, D3, D4: D_SOD-523
D37: UPWR; LED_0603_1608Metric
D38: CHG; LED_0603_1608Metric
D39: SPWR; LED_0603_1608Metric
J1: USB_C_Receptacle_USB2.0_16P; USB_C_Receptacle_GCT_USB4110
J4, J5: Conn_01x02_Pin; PinHeader_1x02_P2.54mm_Vertical_SMD_Pin1Left
L1, L2: 2.2uH; L_1008_2520Metric
R1, R2: 5.1k; R_0603_1608Metric
R3: 1.13k; R_0603_1608Metric
R4: 46.4k; R_0603_1608Metric
R5: 49.9k; R_0603_1608Metric
R6: 200k; R_0603_1608Metric
R7: 1.18k; R_0603_1608Metric
R8, R9, R13: 1.5k; R_0603_1608Metric
R10: 100; R_0603_1608Metric
R11: 732k; R_0603_1608Metric
R12: 100k; R_0603_1608Metric
SW1: MFS126D; SolderPoint_3Pads_2.54x2.54_5.08Spacing
TP25, TP26: TestPoint_2Pole; TestPoint_2Pads_2.5mmx2.5mm_5mmSpacing
U3: BQ24072RGT; VQFN-16-1EP_3x3mm_P0.5mm_EP1.6x1.6mm
U8: TPS63001; Texas_DRC0010J_ThermalVias
U9: TPS61023; SOT-563
U12: TLV73318PDBV; SOT-23-5

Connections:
+1V8: C52.1, U12.5 (OUT); also elsewhere on the board
+3.3V: C15.1, C16.1, C50.1, C51.1, U8.1 (VOUT), U8.10 (FB), U12.1 (IN), U12.3 (EN); also elsewhere on the board
/MCU/CHG_EN1: U3.6 (EN1); also elsewhere on the board
/MCU/CHG_EN2: U3.5 (EN2); also elsewhere on the board
/MCU/CHG_~CE: U3.4 (~CE); also elsewhere on the board
/MCU/CHG_~CHG: D38.1 (K), U3.9 (~CHG); also elsewhere on the board
/MCU/CHG_~PG: D37.1 (K), U3.7 (~PGOOD); also elsewhere on the board
/MCU/USB_DM: D4.1 (K), J1.A7 (D-), J1.B7 (D-); also elsewhere on the board
/MCU/USB_DP: D3.1 (K), J1.A6 (D+), J1.B6 (D+); also elsewhere on the board
/power/CHG_OUT: C11.1, C12.1, SW1.3 (C), U3.10 (OUT), U3.11 (OUT)
unnamed: CON1.1 (POS), U3.2 (BAT), U3.3 (BAT)
unnamed: D1.1 (K), J1.A5 (CC1), R1.1
unnamed: D2.1 (K), J1.B5 (CC2), R2.1
unnamed: D37.2 (A), R8.2
unnamed: D38.2 (A), R9.2
unnamed 112: D39.2 (A), R13.2; also elsewhere on the board
unnamed: J5.1, SW1.1 (A), TP26.1
unnamed: R7.1, U3.12 (ILIM)
unnamed: R3.1, U3.16 (ISET)
unnamed: R4.1, U3.14 (TMR)
unnamed: R5.1, R6.2, U3.1 (TS)
unnamed: C17.1, R10.2, U8.6 (EN), U8.7 (PS/SYNC), U8.8 (VINA)
unnamed: L1.1, U8.4 (L1)
unnamed: L1.2, U8.2 (L2)
unnamed: R11.2, R12.2, U9.1 (FB)
unnamed: L2.1, U9.5 (SW)
VBUS: C1.1, C2.1, C9.1, C10.1, J1.A4 (VBUS), J1.A9 (VBUS), J1.B4 (VBUS), J1.B9 (VBUS), J4.1, R6.1, R8.1, R9.1, TP25.1, U3.13 (IN); also elsewhere on the board
VSYS: C13.1, C14.1, C18.1, C19.1, L2.2, R10.1, R13.1, SW1.2 (B), U8.5 (VIN), U9.2 (EN), U9.3 (VIN); also elsewhere on the board

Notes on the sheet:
5V Power Supply
ESD Protection Diodes (ESD321)
Power Injection Points
USB Connector
3.3V Power Supply
Battery Holder
1.8V Power Supply
Battery Charger / Power Path
Power Injection/Test Points

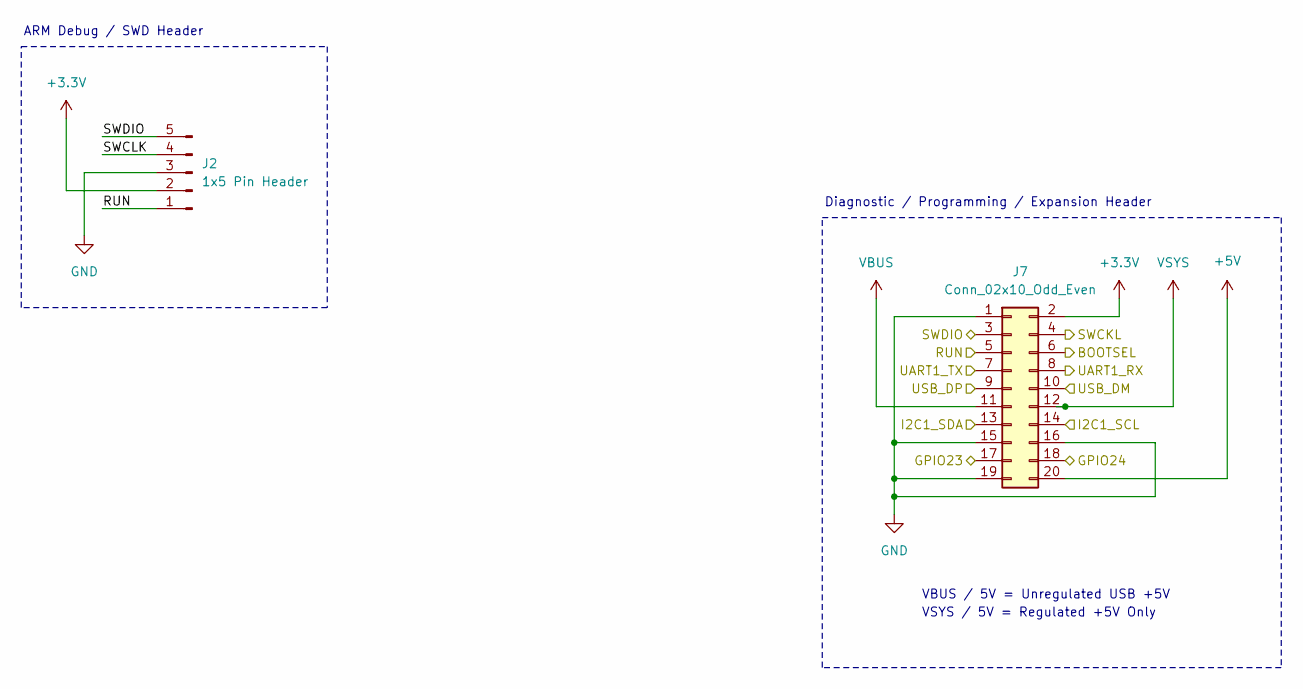
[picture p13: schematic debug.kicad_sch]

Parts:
J2: 1x5 Pin Header; PinHeader_1x05_P2.54mm_Vertical_SMD_Pin1Left
J7: Conn_02x10_Odd_Even; PinHeader_2x10_P2.54mm_Vertical_SMD

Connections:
+3.3V: J2.2, J7.2; also elsewhere on the board
/LED/I2C1_SCL: J7.14; also elsewhere on the board
/LED/I2C1_SDA: J7.13; also elsewhere on the board
/MCU/BOOTSEL: J7.6; also elsewhere on the board
/MCU/GPIO23: J7.17; also elsewhere on the board
/MCU/GPIO24: J7.18; also elsewhere on the board
/MCU/SWCLK: J7.4; also elsewhere on the board
/MCU/UART1_RX: J7.8; also elsewhere on the board
/MCU/UART1_TX: J7.7; also elsewhere on the board
/MCU/USB_DM: J7.10; also elsewhere on the board
/MCU/USB_DP: J7.9; also elsewhere on the board
/debug/RUN: J2.1, J7.5; also elsewhere on the board
/debug/SWCLK: J2.4
/debug/SWDIO: J2.5, J7.3; also elsewhere on the board
VBUS: J7.11; also elsewhere on the board
VSYS: J7.12; also elsewhere on the board

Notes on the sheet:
VBUS / 5V = Unregulated USB +5V
Diagnostic / Programming / Expansion Header
VSYS / 5V = Regulated +5V Only
ARM Debug / SWD Header

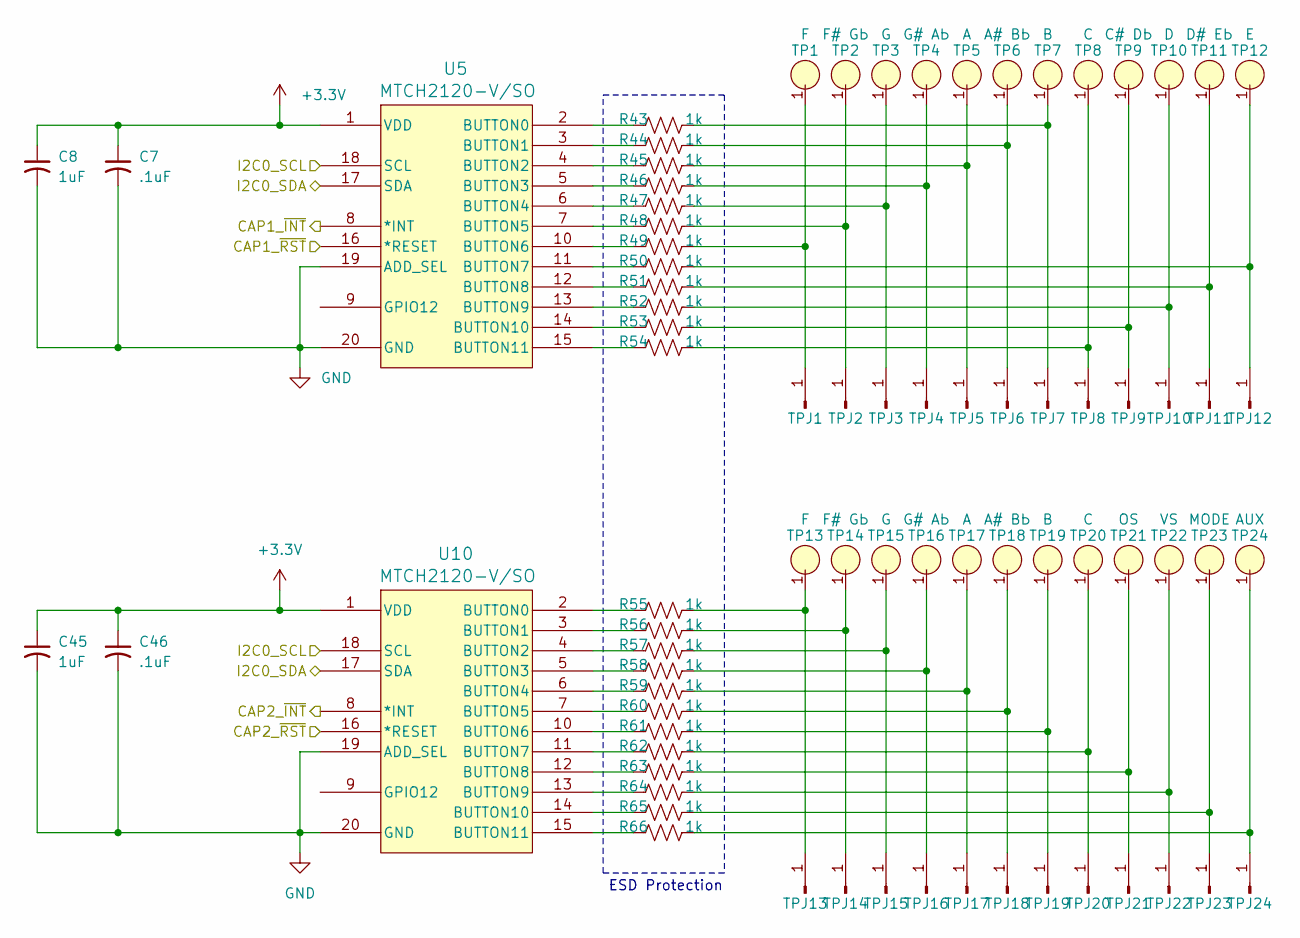
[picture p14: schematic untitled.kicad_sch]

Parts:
C7, C46: .1uF; C_0603_1608Metric
C8, C45: 1uF; C_0603_1608Metric
R43, R44, R45, R46, R47, R48, R49, R50, R51, R52, R53, R54, R55, R56, R57, R58, R59, R60, R61, R62, R63, R64, R65, R66: 1k; R_0603_1608Metric
TP1, TP13: F; Touchpad_WhiteKey
TP2, TP14: F# GЬ; Touchpad_BlackKey
TP3, TP15: G; Touchpad_WhiteKey
TP4, TP16: G# AЬ; Touchpad_BlackKey
TP5, TP17: A; Touchpad_WhiteKey
TP6, TP18: A# BЬ; Touchpad_BlackKey
TP7, TP19: B; Touchpad_WhiteKey
TP8, TP20: C; Touchpad_WhiteKey
TP9: C# DЬ; Touchpad_BlackKey
TP10: D; Touchpad_WhiteKey
TP11: D# EЬ; Touchpad_BlackKey
TP12: E; Touchpad_WhiteKey
TP21: OS; Touchpad_Circle_10mm
TP22: VS; Touchpad_Circle_10mm
TP23: MODE; Touchpad_Circle_10mm
TP24: AUX; Touchpad_Circle_10mm
TPJ1, TPJ2, TPJ3, TPJ4, TPJ5, TPJ6, TPJ7, TPJ8, TPJ9, TPJ10, TPJ11, TPJ12, TPJ13, TPJ14, TPJ15, TPJ16, TPJ17, TPJ18, TPJ19, TPJ20, TPJ21, TPJ22, TPJ23, TPJ24: Conn_01x01_Pin; Terminal_SMD_.250in
U5, U10: MTCH2120-V/SO; SOIC-20W_7.5x12.8mm_P1.27mm

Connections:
+3.3V: C7.1, C8.1, C45.1, C46.1, U5.1 (VDD), U10.1 (VDD); also elsewhere on the board
/MCU/CAP1_~INT: U5.8 (*INT); also elsewhere on the board
/MCU/CAP1_~RST: U5.16 (*RESET); also elsewhere on the board
/MCU/CAP2_~INT: U10.8 (*INT); also elsewhere on the board
/MCU/CAP2_~RST: U10.16 (*RESET); also elsewhere on the board
/MCU/I2C0_SCL: U5.18 (SCL), U10.18 (SCL); also elsewhere on the board
/MCU/I2C0_SDA: U5.17 (SDA), U10.17 (SDA); also elsewhere on the board
unnamed: R49.2, TP1.1, TPJ1.1 (Pin_1_1)
unnamed: R48.2, TP2.1, TPJ2.1 (Pin_1_1)
unnamed: R47.2, TP3.1, TPJ3.1 (Pin_1_1)
unnamed: R46.2, TP4.1, TPJ4.1 (Pin_1_1)
unnamed: R45.2, TP5.1, TPJ5.1 (Pin_1_1)
unnamed: R44.2, TP6.1, TPJ6.1 (Pin_1_1)
unnamed: R43.2, TP7.1, TPJ7.1 (Pin_1_1)
unnamed: R54.2, TP8.1, TPJ8.1 (Pin_1_1)
unnamed: R53.2, TP9.1, TPJ9.1 (Pin_1_1)
unnamed: R52.2, TP10.1, TPJ10.1 (Pin_1_1)
unnamed: R51.2, TP11.1, TPJ11.1 (Pin_1_1)
unnamed: R50.2, TP12.1, TPJ12.1 (Pin_1_1)
unnamed: R55.2, TP13.1, TPJ13.1 (Pin_1_1)
unnamed: R56.2, TP14.1, TPJ14.1 (Pin_1_1)
unnamed: R57.2, TP15.1, TPJ15.1 (Pin_1_1)
unnamed: R58.2, TP16.1, TPJ16.1 (Pin_1_1)
unnamed: R59.2, TP17.1, TPJ17.1 (Pin_1_1)
unnamed: R60.2, TP18.1, TPJ18.1 (Pin_1_1)
unnamed: R61.2, TP19.1, TPJ19.1 (Pin_1_1)
unnamed: R62.2, TP20.1, TPJ20.1 (Pin_1_1)
unnamed: R63.2, TP21.1, TPJ21.1 (Pin_1_1)
unnamed: R64.2, TP22.1, TPJ22.1 (Pin_1_1)
unnamed: R65.2, TP23.1, TPJ23.1 (Pin_1_1)
unnamed: R66.2, TP24.1, TPJ24.1 (Pin_1_1)
unnamed: R43.1, U5.2 (BUTTON0)
unnamed: R44.1, U5.3 (BUTTON1)
unnamed: R45.1, U5.4 (BUTTON2)
unnamed: R46.1, U5.5 (BUTTON3)
unnamed: R47.1, U5.6 (BUTTON4)
unnamed: R48.1, U5.7 (BUTTON5)
unnamed: R49.1, U5.10 (BUTTON6)
unnamed: R50.1, U5.11 (BUTTON7)
unnamed: R51.1, U5.12 (BUTTON8)
unnamed: R52.1, U5.13 (BUTTON9)
unnamed: R53.1, U5.14 (BUTTON10)
unnamed: R54.1, U5.15 (BUTTON11)
unnamed: R55.1, U10.2 (BUTTON0)
unnamed: R56.1, U10.3 (BUTTON1)
unnamed: R57.1, U10.4 (BUTTON2)
unnamed: R58.1, U10.5 (BUTTON3)
unnamed: R59.1, U10.6 (BUTTON4)
unnamed: R60.1, U10.7 (BUTTON5)
unnamed: R61.1, U10.10 (BUTTON6)
unnamed: R62.1, U10.11 (BUTTON7)
unnamed: R63.1, U10.12 (BUTTON8)
unnamed: R64.1, U10.13 (BUTTON9)
unnamed: R65.1, U10.14 (BUTTON10)
unnamed: R66.1, U10.15 (BUTTON11)

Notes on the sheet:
ESD Protection

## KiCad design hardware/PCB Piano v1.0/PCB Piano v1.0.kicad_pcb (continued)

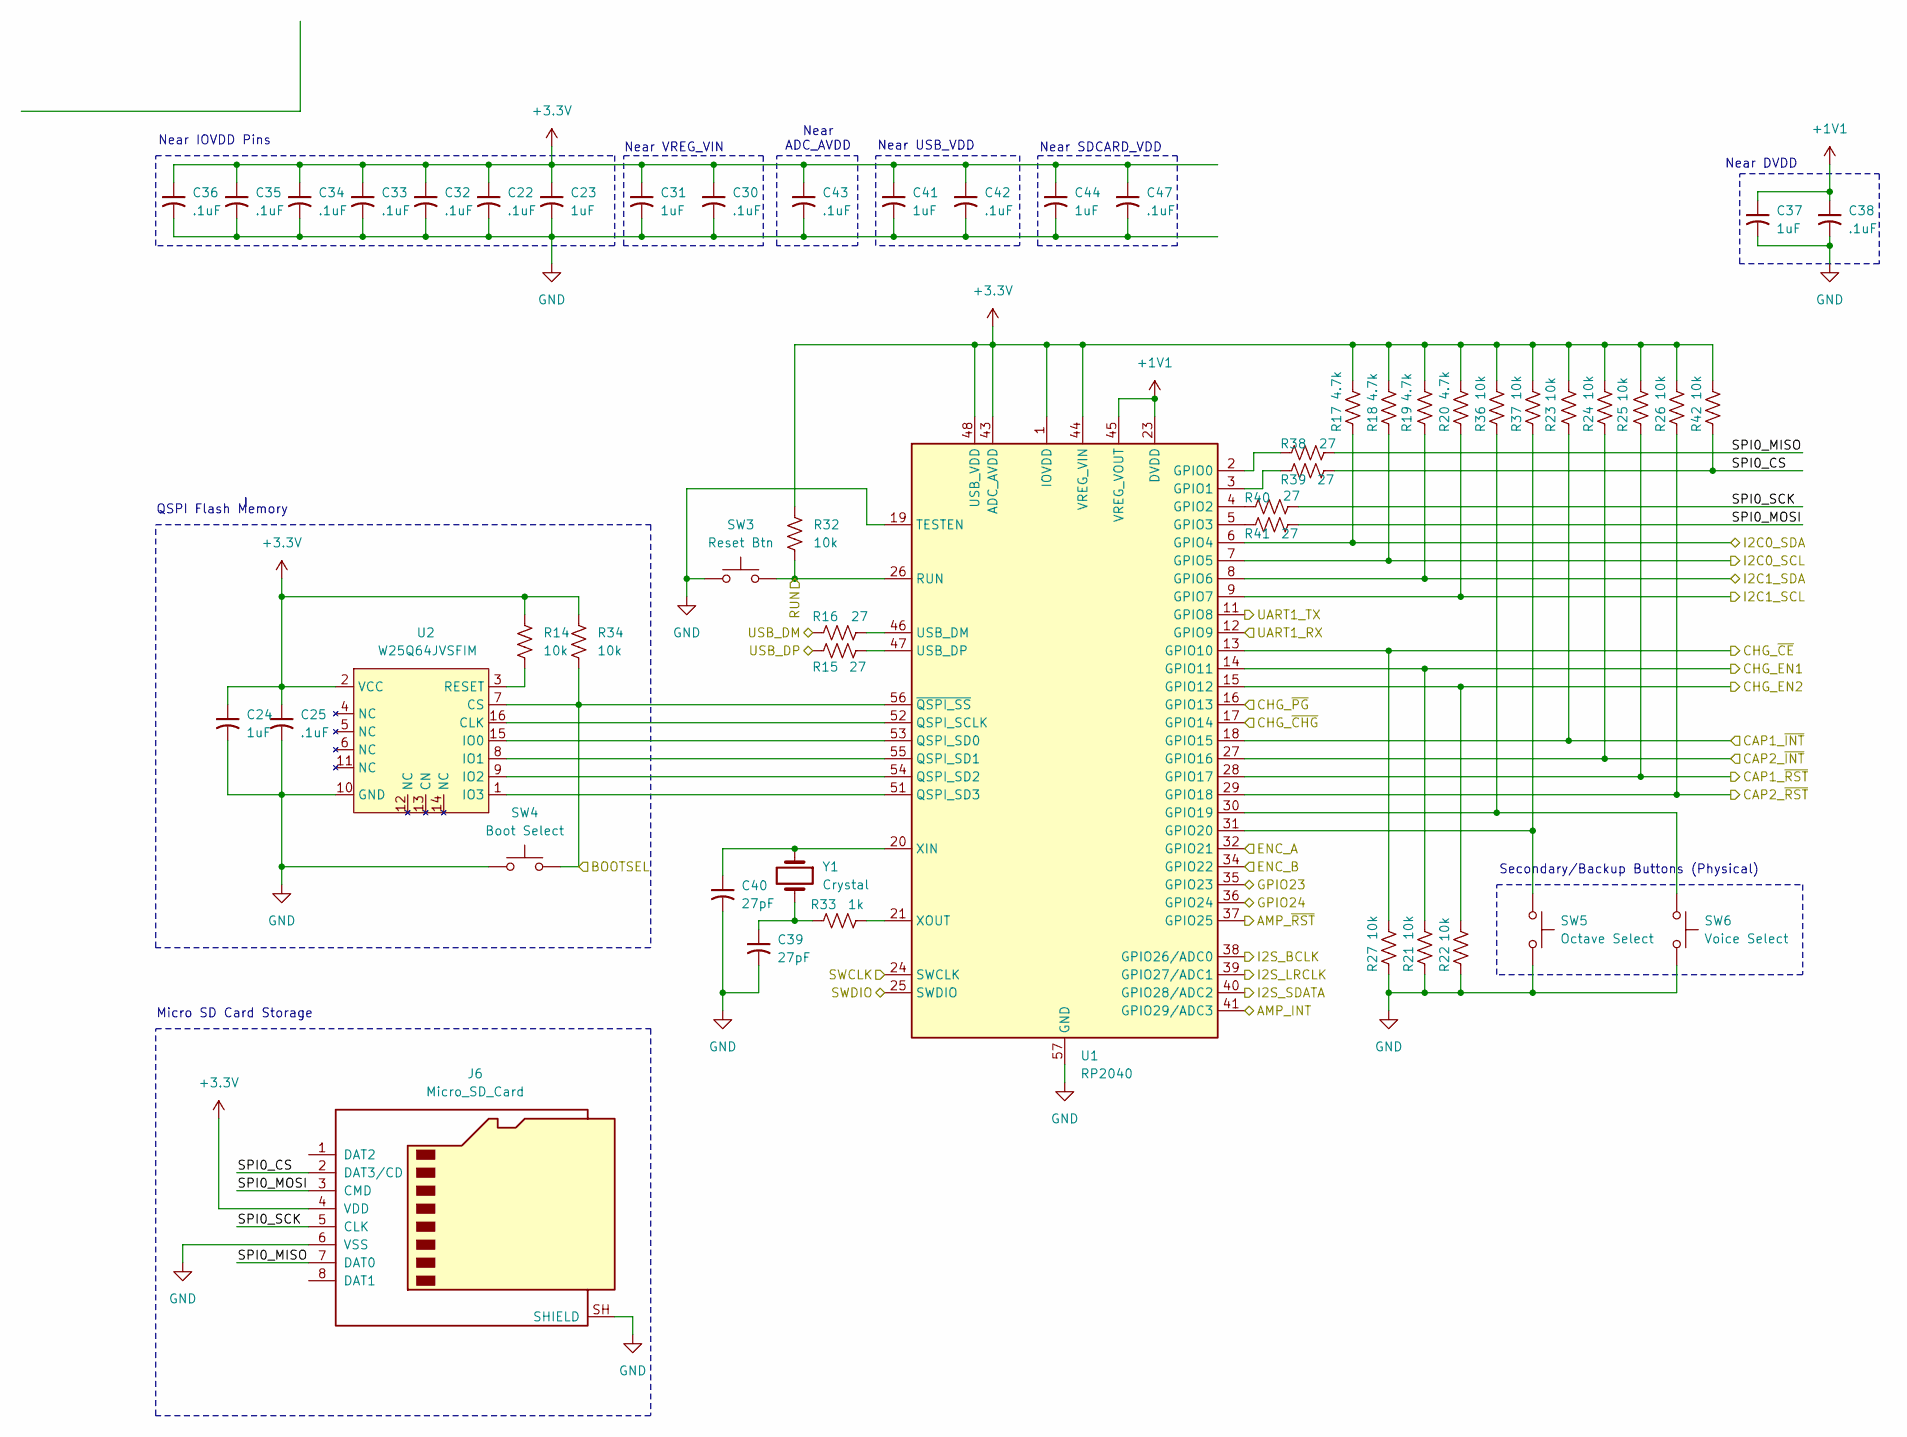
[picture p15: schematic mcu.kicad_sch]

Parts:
C22, C25, C30, C32, C33, C34, C35, C36, C38, C42, C43, C47: .1uF; C_0603_1608Metric
C23, C24, C31, C37, C41, C44: 1uF; C_0603_1608Metric
C39, C40: 27pF; C_0603_1608Metric
J6: Micro_SD_Card; microSD_HC_Hirose_DM3D-SF
R14, R21, R22, R23, R24, R25, R26, R27, R32, R34, R36, R37, R42: 10k; R_0603_1608Metric
R15, R16, R38, R39, R40, R41: 27; R_0603_1608Metric
R17, R18, R19, R20: 4.7k; R_0603_1608Metric
R33: 1k; R_0603_1608Metric
SW3: Reset Btn; Button_Push_KMR6
SW4: Boot Select; Button_Push_KMR6
SW5: Octave Select; Button_Push_KMR6
SW6: Voice Select; Button_Push_KMR6
U1: RP2040; QFN-56-1EP_7x7mm_P0.4mm_EP3.2x3.2mm
U2: W25Q64JVSFIM; SOIC-16W_7.5x10.3mm_P1.27mm
Y1: Crystal; Crystal_SMD_Abracon_ABM8G-4Pin_3.2x2.5mm

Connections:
+1V1: C37.1, C38.1, U1.23 (DVDD), U1.45 (VREG_VOUT), U1.50 (DVDD)
+3.3V: C22.1, C23.1, C24.1, C25.1, C30.1, C31.1, C32.1, C33.1, C34.1, C35.1, C36.1, C41.1, C42.1, C43.1, C44.1, C47.1, J6.4 (VDD), R14.1, R17.1, R18.1, R19.1, R20.1, R23.1, R24.1, R25.1, R26.1, R32.1, R34.1, R36.1, R37.1, R42.1, U1.1 (IOVDD), U1.10 (IOVDD), U1.22 (IOVDD), U1.33 (IOVDD), U1.42 (IOVDD), U1.43 (ADC_AVDD), U1.44 (VREG_VIN), U1.48 (USB_VDD), U1.49 (IOVDD), U2.2 (VCC); also elsewhere on the board
/LED/I2C1_SCL: R20.2, U1.9 (GPIO7); also elsewhere on the board
/LED/I2C1_SDA: R19.2, U1.8 (GPIO6); also elsewhere on the board
/MCU/AMP_INT: U1.41 (GPIO29/ADC3); also elsewhere on the board
/MCU/AMP_~RST: U1.37 (GPIO25); also elsewhere on the board
/MCU/BOOTSEL: R34.2, SW4.2, U1.56 (~QSPI_SS), U2.7 (CS); also elsewhere on the board
/MCU/CAP1_~INT: R23.2, U1.18 (GPIO15); also elsewhere on the board
/MCU/CAP1_~RST: R25.2, U1.28 (GPIO17); also elsewhere on the board
/MCU/CAP2_~INT: R24.2, U1.27 (GPIO16); also elsewhere on the board
/MCU/CAP2_~RST: R26.2, U1.29 (GPIO18); also elsewhere on the board
/MCU/CHG_EN1: R21.1, U1.14 (GPIO11); also elsewhere on the board
/MCU/CHG_EN2: R22.1, U1.15 (GPIO12); also elsewhere on the board
/MCU/CHG_~CE: R27.1, U1.13 (GPIO10); also elsewhere on the board
/MCU/CHG_~CHG: U1.17 (GPIO14); also elsewhere on the board
/MCU/CHG_~PG: U1.16 (GPIO13); also elsewhere on the board
/MCU/ENC_A: U1.32 (GPIO21); also elsewhere on the board
/MCU/ENC_B: U1.34 (GPIO22); also elsewhere on the board
/MCU/GPIO23: U1.35 (GPIO23); also elsewhere on the board
/MCU/GPIO24: U1.36 (GPIO24); also elsewhere on the board
/MCU/I2C0_SCL: R18.2, U1.7 (GPIO5); also elsewhere on the board
/MCU/I2C0_SDA: R17.2, U1.6 (GPIO4); also elsewhere on the board
/MCU/I2S_BCLK: U1.38 (GPIO26/ADC0); also elsewhere on the board
/MCU/I2S_LRCLK: U1.39 (GPIO27/ADC1); also elsewhere on the board
/MCU/I2S_SDATA: U1.40 (GPIO28/ADC2); also elsewhere on the board
/MCU/SPI0_CS: J6.2 (DAT3/CD), R39.1, R42.2
/MCU/SPI0_MISO: J6.7 (DAT0), R38.1
/MCU/SPI0_MOSI: J6.3 (CMD), R41.1
/MCU/SPI0_SCK: J6.5 (CLK), R40.1
/MCU/SWCLK: U1.24 (SWCLK); also elsewhere on the board
/MCU/UART1_RX: U1.12 (GPIO9); also elsewhere on the board
/MCU/UART1_TX: U1.11 (GPIO8); also elsewhere on the board
/MCU/USB_DM: R16.2; also elsewhere on the board
/MCU/USB_DP: R15.2; also elsewhere on the board
/debug/RUN: R32.2, SW3.2, U1.26 (RUN); also elsewhere on the board
/debug/SWDIO: U1.25 (SWDIO); also elsewhere on the board
unnamed: C39.1, R33.1, Y1.2
unnamed: R38.2, U1.2 (GPIO0)
unnamed: R39.2, U1.3 (GPIO1)
unnamed: R40.2, U1.4 (GPIO2)
unnamed: R41.2, U1.5 (GPIO3)
unnamed: R36.2, SW6.1, U1.30 (GPIO19)
unnamed: R37.2, SW5.1, U1.31 (GPIO20)
unnamed: U1.52 (QSPI_SCLK), U2.16 (CLK)
unnamed: U1.53 (QSPI_SD0), U2.15 (IO0)
unnamed: U1.55 (QSPI_SD1), U2.8 (IO1)
unnamed: U1.54 (QSPI_SD2), U2.9 (IO2)
unnamed: U1.51 (QSPI_SD3), U2.1 (IO3)
unnamed: R16.1, U1.46 (USB_DM)
unnamed: R15.1, U1.47 (USB_DP)
unnamed: C40.1, U1.20 (XIN), Y1.1
unnamed: R33.2, U1.21 (XOUT)
unnamed: R14.2, U2.3 (RESET)

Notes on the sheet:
Near VREG_VIN
Near DVDD
Near IOVDD Pins
Secondary/Backup Buttons (Physical)
Micro SD Card Storage
Near USB_VDD
Near ADC_AVDD
Near SDCARD_VDD
QSPI Flash Memory

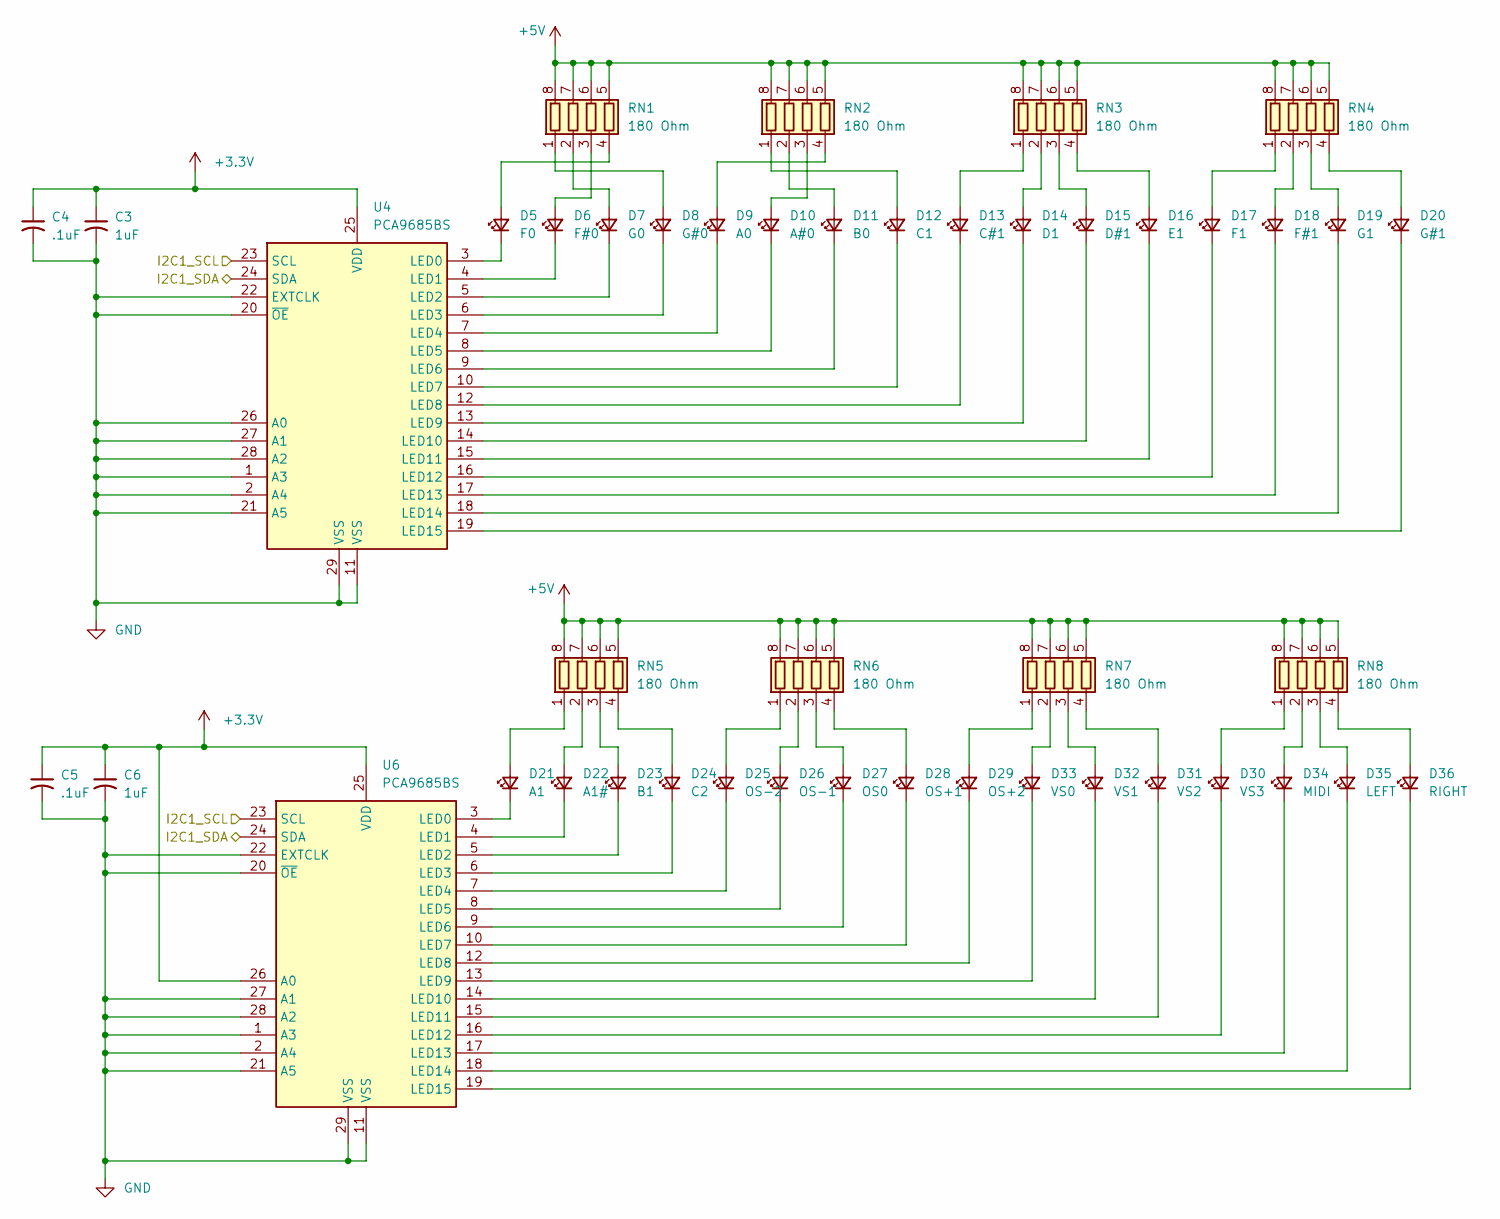
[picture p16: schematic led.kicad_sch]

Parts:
C3, C6: 1uF; C_0603_1608Metric
C4, C5: .1uF; C_0603_1608Metric
D5: F0; LED_0603_1608Metric
D6: F#0; LED_0603_1608Metric
D7: G0; LED_0603_1608Metric
D8: G#0; LED_0603_1608Metric
D9: A0; LED_0603_1608Metric
D10: A#0; LED_0603_1608Metric
D11: B0; LED_0603_1608Metric
D12: C1; LED_0603_1608Metric
D13: C#1; LED_0603_1608Metric
D14: D1; LED_0603_1608Metric
D15: D#1; LED_0603_1608Metric
D16: E1; LED_0603_1608Metric
D17: F1; LED_0603_1608Metric
D18: F#1; LED_0603_1608Metric
D19: G1; LED_0603_1608Metric
D20: G#1; LED_0603_1608Metric
D21: A1; LED_0603_1608Metric
D22: A1#; LED_0603_1608Metric
D23: B1; LED_0603_1608Metric
D24: C2; LED_0603_1608Metric
D25: OS-2; LED_0603_1608Metric
D26: OS-1; LED_0603_1608Metric
D27: OS0; LED_0603_1608Metric
D28: OS+1; LED_0603_1608Metric
D29: OS+2; LED_0603_1608Metric
D30: VS3; LED_0603_1608Metric
D31: VS2; LED_0603_1608Metric
D32: VS1; LED_0603_1608Metric
D33: VS0; LED_0603_1608Metric
D34: MIDI; LED_0603_1608Metric
D35: LEFT; LED_0603_1608Metric
D36: RIGHT; LED_0603_1608Metric
RN1, RN2, RN3, RN4, RN5, RN6, RN7, RN8: 180 Ohm; R_Array_Convex_4x1206
U4, U6: PCA9685BS; NXP_HVQFN-28_6mmx6mmx0.85mm

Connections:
+3.3V: C3.1, C4.1, C5.1, C6.1, U4.25 (VDD), U6.25 (VDD), U6.26 (A0); also elsewhere on the board
/LED/I2C1_SCL: U4.23 (SCL), U6.23 (SCL); also elsewhere on the board
/LED/I2C1_SDA: U4.24 (SDA), U6.24 (SDA); also elsewhere on the board
unnamed: D5.2 (A), RN1.4 (R4.1)
unnamed: D5.1 (K), U4.3 (LED0)
unnamed: D6.2 (A), RN1.3 (R3.1)
unnamed: D6.1 (K), U4.4 (LED1)
unnamed: D7.2 (A), RN1.2 (R2.1)
unnamed: D7.1 (K), U4.5 (LED2)
unnamed: D8.2 (A), RN1.1 (R1.1)
unnamed: D8.1 (K), U4.6 (LED3)
unnamed: D9.2 (A), RN2.4 (R4.1)
unnamed: D9.1 (K), U4.7 (LED4)
unnamed: D10.2 (A), RN2.3 (R3.1)
unnamed: D10.1 (K), U4.8 (LED5)
unnamed: D11.2 (A), RN2.2 (R2.1)
unnamed: D11.1 (K), U4.9 (LED6)
unnamed: D12.2 (A), RN2.1 (R1.1)
unnamed: D12.1 (K), U4.10 (LED7)
unnamed: D13.2 (A), RN3.1 (R1.1)
unnamed: D13.1 (K), U4.12 (LED8)
unnamed: D14.2 (A), RN3.2 (R2.1)
unnamed: D14.1 (K), U4.13 (LED9)
unnamed: D15.2 (A), RN3.3 (R3.1)
unnamed: D15.1 (K), U4.14 (LED10)
unnamed: D16.2 (A), RN3.4 (R4.1)
unnamed: D16.1 (K), U4.15 (LED11)
unnamed: D17.2 (A), RN4.1 (R1.1)
unnamed: D17.1 (K), U4.16 (LED12)
unnamed: D18.2 (A), RN4.2 (R2.1)
unnamed: D18.1 (K), U4.17 (LED13)
unnamed: D19.2 (A), RN4.3 (R3.1)
unnamed: D19.1 (K), U4.18 (LED14)
unnamed: D20.2 (A), RN4.4 (R4.1)
unnamed: D20.1 (K), U4.19 (LED15)
unnamed: D21.2 (A), RN5.1 (R1.1)
unnamed: D21.1 (K), U6.3 (LED0)
unnamed: D22.2 (A), RN5.2 (R2.1)
unnamed: D22.1 (K), U6.4 (LED1)
unnamed: D23.2 (A), RN5.3 (R3.1)
unnamed: D23.1 (K), U6.5 (LED2)
unnamed: D24.2 (A), RN5.4 (R4.1)
unnamed: D24.1 (K), U6.6 (LED3)
unnamed: D25.2 (A), RN6.1 (R1.1)
unnamed: D25.1 (K), U6.7 (LED4)
unnamed: D26.2 (A), RN6.2 (R2.1)
unnamed: D26.1 (K), U6.8 (LED5)
unnamed: D27.2 (A), RN6.3 (R3.1)
unnamed: D27.1 (K), U6.9 (LED6)
unnamed: D28.2 (A), RN6.4 (R4.1)
unnamed: D28.1 (K), U6.10 (LED7)
unnamed: D29.2 (A), RN7.1 (R1.1)
unnamed: D29.1 (K), U6.12 (LED8)
unnamed: D30.2 (A), RN8.1 (R1.1)
unnamed: D30.1 (K), U6.16 (LED12)
unnamed: D31.2 (A), RN7.4 (R4.1)
unnamed: D31.1 (K), U6.15 (LED11)
unnamed: D32.2 (A), RN7.3 (R3.1)
unnamed: D32.1 (K), U6.14 (LED10)
unnamed: D33.2 (A), RN7.2 (R2.1)
unnamed: D33.1 (K), U6.13 (LED9)
unnamed: D34.2 (A), RN8.2 (R2.1)
unnamed: D34.1 (K), U6.17 (LED13)
unnamed: D35.2 (A), RN8.3 (R3.1)
unnamed: D35.1 (K), U6.18 (LED14)
unnamed: D36.2 (A), RN8.4 (R4.1)
unnamed: D36.1 (K), U6.19 (LED15)

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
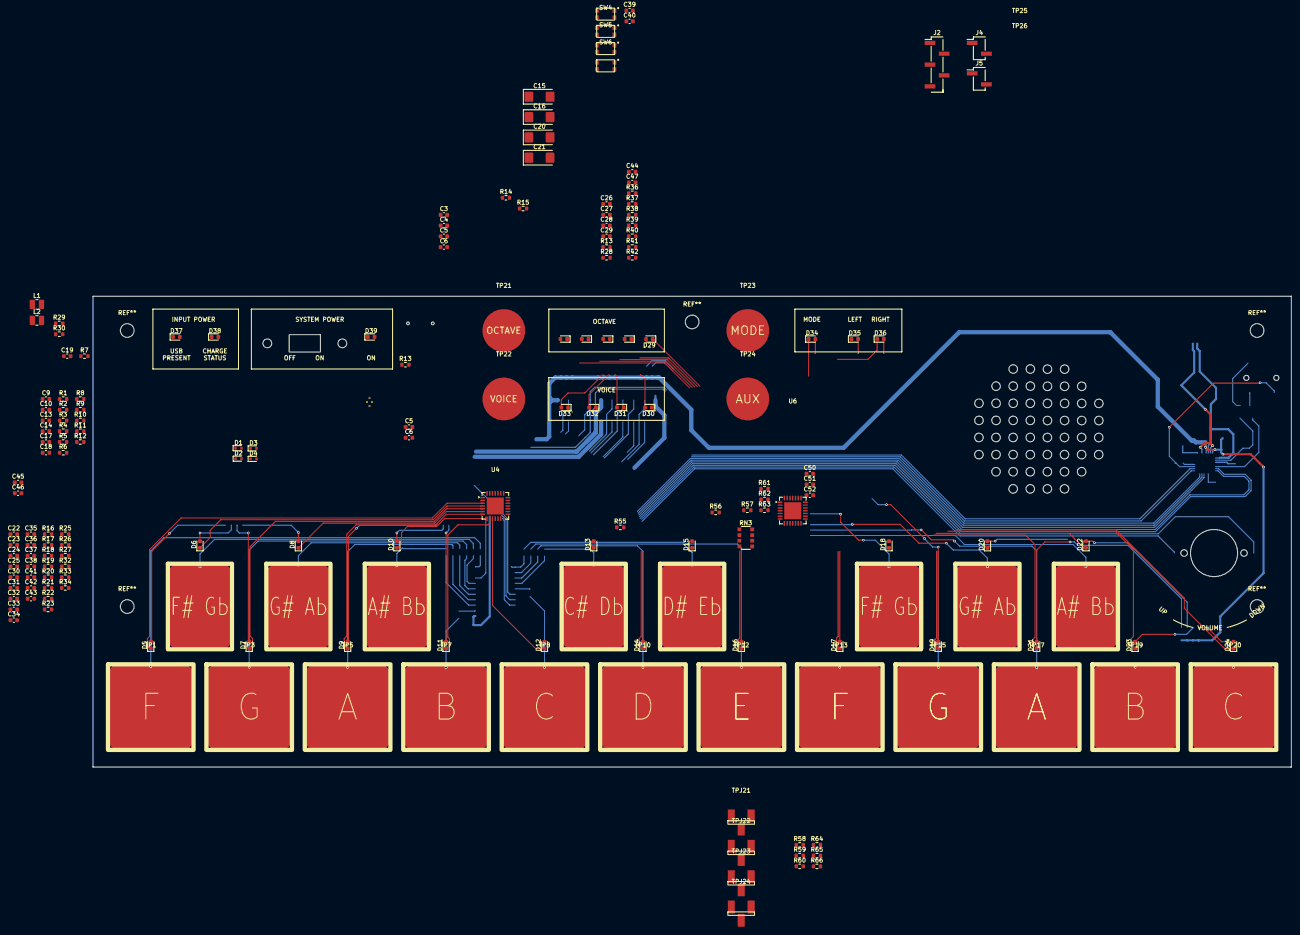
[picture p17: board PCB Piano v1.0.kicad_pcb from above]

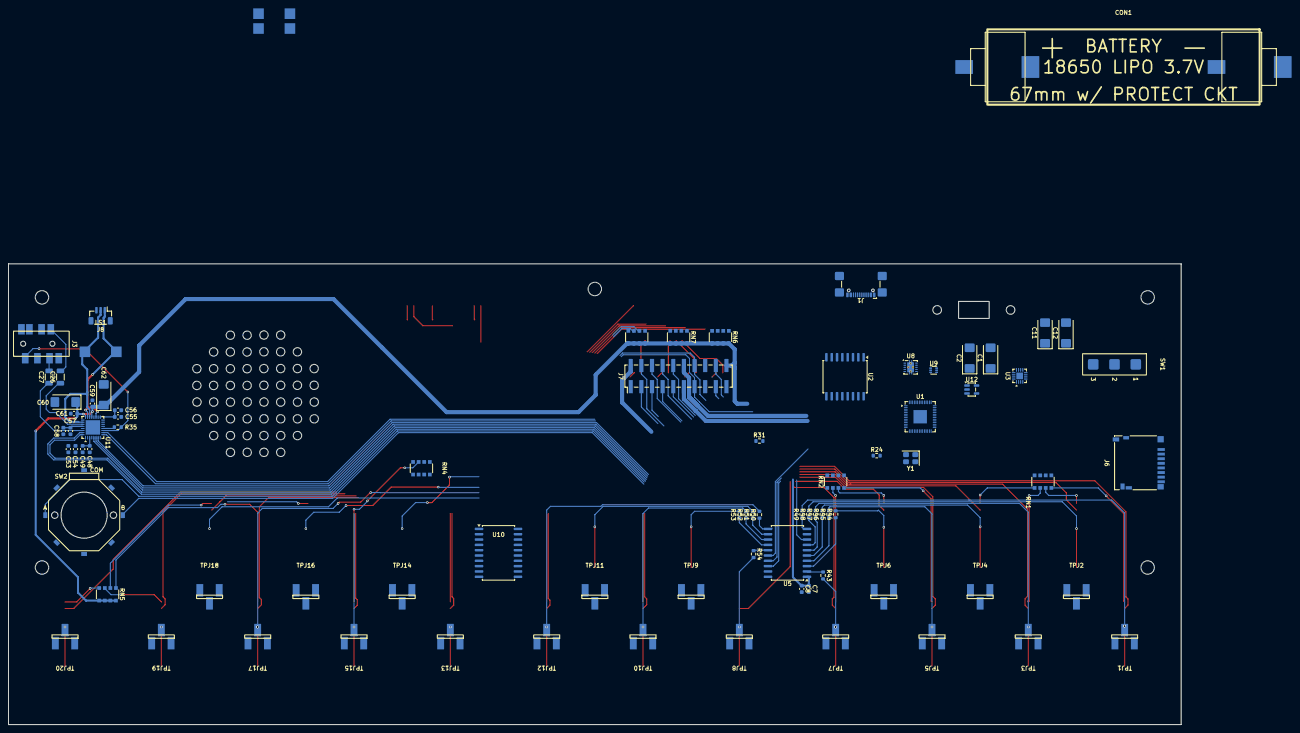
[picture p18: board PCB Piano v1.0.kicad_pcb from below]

Board: 2 copper layers, 280.0 x 110.0 mm, 260 parts (81 on the bottom side), 198 nets.

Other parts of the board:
C5#2: .1uF; C_0603_1608Metric
C6#2: 1uF; C_0603_1608Metric
C26#2, C27#2: 100uF; C_1206_3216Metric
R13#2: 1.5k; R_0603_1608Metric

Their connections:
+3.3V: C5#2.1, C6#2.1; also elsewhere on the board
unnamed 112: R13#2.2; also elsewhere on the board
VSYS: R13#2.1; also elsewhere on the board

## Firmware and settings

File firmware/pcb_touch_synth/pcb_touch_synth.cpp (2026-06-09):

#include <stdio.h>

#include "pico/stdlib.h"

// ======================================================
// PCB TOUCH SYNTH — MAIN ENTRY POINT
//
// Two-core architecture:
//   Core 0 (this file / system_tasks):
//     Touch input, LED output, USB MIDI, power management,
//     debug console, voice/bank/octave selection, SysEx transfer drain.
//
//   Core 1 (launched by audio_core_start_on_core1):
//     I2S audio render loop (oscillator synthesis, ADSR, DMA fill) when
//     in local synthesis mode.  Idle in MIDI mode; used for SysEx file
//     transfer (SD card read → ring buffer) when a transfer is active.
//
// STARTUP SEQUENCE
//   stdio_init_all()       — UART auto-init on GPIO 12/13 (pico_enable_stdio_uart=1)
//   debug_console_init()   — register command handlers
//   status_led_init()      — Dotstar LEDs via SPI0; must precede the USB wait
//   debug_usb_serial_wait()— timed wait (DEBUG_USB_SERIAL_WAIT_MS) so a UART
//                            terminal can connect before boot logs begin
//   system_init()          — full hardware + subsystem initialisation on core 0
//   audio_core_start_on_core1() — launches core 1 render loop (called inside system_init)
//   system_tasks() loop    — core 0 runs forever servicing all non-audio tasks
// ======================================================

#include "config/firmware_config.h"
#include "debug/debug_console.h"

#include "system/status_led.h"
#include "system/system_init.h"
#include "system/system_tasks.h"

static void debug_usb_serial_wait();

int main()
{
    stdio_init_all();

#if ENABLE_DEBUG_CONSOLE
    debug_console_init();
#endif

    // status_led_init() must run before debug_usb_serial_wait() because
    // the wait loop calls status_led_task() (Dotstar SPI write).
    status_led_init();

    // Timed wait so a UART terminal can connect before boot log output begins.
    // Configured by DEBUG_USB_SERIAL_WAIT_MS in firmware_config.h.
    // Set to 0 to skip for production builds.
    debug_usb_serial_wait();

    printf("\n\n");
    printf("=====================================\n");
    printf(" PCB Piano RP2040 firmware starting  \n");
    printf("=====================================\n");

    if (!system_init()) {
        printf("System initialization failed.\n");

        status_led_set(SYSTEM_STATUS_FAULT);

        while (true) {
            status_led_task();
            sleep_ms(10);
        }
    }

    // Core 1 is running audio_core1_main() from this point.
    // Core 0 runs the task loop forever.
    while (true) {
        system_tasks();
        sleep_ms(1);
    }
}

static void debug_usb_serial_wait()
{
#if ENABLE_DEBUG_BOOT_LOGS
    uint32_t start = to_ms_since_boot(get_absolute_time());

    while ((to_ms_since_boot(get_absolute_time()) - start) < DEBUG_USB_SERIAL_WAIT_MS) {
        status_led_task();
        sleep_ms(10);
    }
#endif
}

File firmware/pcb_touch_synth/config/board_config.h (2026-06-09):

#pragma once

// ======================================================
// BOARD PIN CONFIGURATION
//
// Central GPIO pin map for the PCB Piano RP2040 board.
// All peripheral drivers reference these defines — change
// a pin here and it propagates to the entire firmware.
//
// Hardware overview:
//   MCU:     RP2040 (dual-core Cortex-M0+, 133MHz)
//   Flash:   128Mbit QSPI external flash
//   I2C0:    Touch controllers    (PIN_I2C0_SDA / PIN_I2C0_SCL)
//   I2C1:    Audio, Power, LEDs   (PIN_I2C1_SDA / PIN_I2C1_SCL)
//   SPI0:    SD card + DotStar LEDs share bus
//            (PIN_SPI0_SCK / PIN_SPI0_TX / PIN_SPI0_RX / PIN_SPI0_CS_SD)
//            DotStar uses PIN_DOTSTAR_CLK / PIN_DOTSTAR_DATA (same physical pins as SPI0 SCK/TX)
//   SD det:  PIN_SD_CARD_DETECT — active-LOW, 10kΩ pull-up on PCB
//   I2S out: DAC audio output  (PIN_AUDIO_I2S_BCLK / PIN_AUDIO_I2S_LRCLK / PIN_AUDIO_I2S_DATA)
//   I2S in:  MEMS mic input    (PIN_MIC_I2S_DATA, shares BCLK/LRCLK with the DAC output)
//   UART:    Debug header       (UART_TX_PIN / UART_RX_PIN, not yet enabled in firmware)
//
// GPIO ALLOCATION SUMMARY (RP2040 GPIO 0-29)
//   0  SPI0_RX       1  SPI0_CS_SD    2  SPI0_SCK/DOTSTAR_CLK  3  SPI0_TX/DOTSTAR_DATA
//   4  I2C0_SDA      5  I2C0_SCL      6  I2C1_SDA              7  I2C1_SCL
//   8  SD_CARD_DETECT  9  CHARGER_IRQ  10  USB_MUX_SEL         11  DEBUG_GPIO11
//  12  UART_TX       13 UART_RX       14  (unassigned)          15  TOUCH1_IRQ
//  16  TOUCH2_IRQ   17  TOUCH_RESET  18  DOTSTAR_ENABLE         19  5V_EN
//  20  LED_EN        21 AUDIO_VOL_A  22  AUDIO_VOL_B            23  MIC_I2S_DATA
//  24  DEBUG_GPIO24  25 AUDIO_RESET  26  AUDIO_I2S_BCLK         27  AUDIO_I2S_LRCLK
//  28  AUDIO_I2S_DATA  29 AUDIO_IRQ
// ======================================================

// ======================================================
// I2C BUSES
// ======================================================

// I2C0
#define PIN_I2C0_SDA    4
#define PIN_I2C0_SCL    5

// I2C1
#define PIN_I2C1_SDA    6
#define PIN_I2C1_SCL    7

// ======================================================
// SPI BUS
// ======================================================

#define PIN_SPI0_SCK    2
#define PIN_SPI0_TX     3
#define PIN_SPI0_RX     0
#define PIN_SPI0_CS_SD  1

// ======================================================
// DOTSTAR STATUS LEDS
// ======================================================

#define PIN_DOTSTAR_CLK     2
#define PIN_DOTSTAR_DATA    3
#define PIN_DOTSTAR_ENABLE  18

// ======================================================
// LED CONTROLLERS
// ======================================================

#define PIN_LED_EN      20

// ======================================================
// TOUCH CONTROLLER
// ======================================================

#define PIN_TOUCH1_IRQ    15
#define PIN_TOUCH2_IRQ    16
#define PIN_TOUCH_RESET   17

// ======================================================
// AUDIO
// ======================================================

#define PIN_AUDIO_I2S_BCLK      26
#define PIN_AUDIO_I2S_LRCLK     27
#define PIN_AUDIO_I2S_DATA      28
#define PIN_AUDIO_RESET         25
#define PIN_AUDIO_IRQ           29

#define PIN_AUDIO_VOL_A         21
#define PIN_AUDIO_VOL_B         22

// ======================================================
// MICROPHONE I2S INPUT (ICS-43432)
//
// PIN_MIC_I2S_DATA is the mic's SD output (data back to RP2040).
// The mic shares PIN_AUDIO_I2S_BCLK and PIN_AUDIO_I2S_LRCLK with
// the TLV320DAC3100 DAC — both devices see the same BCLK and WCLK
// from the RP2040 I2S master at AUDIO_BCLK_HZ (44100 × 64 = 2,822,400 Hz).
//
// Hardwired on PCB (no MCU GPIO needed):
//   CONFIG pin → GND   (required by ICS-43432 datasheet)
//   LR pin     → 3V3   (mic outputs on RIGHT channel; data follows WS rising edge)
// The SD line has a 100kΩ pull-down to GND (confirmed on PCB).
// ======================================================

#define PIN_MIC_I2S_DATA        23

// ======================================================
// BATTERY CHARGER / POWER PATH
// ======================================================

#define PIN_CHARGER_IRQ          9
#define PIN_USB_MUX_SEL         10
#define PIN_5V_EN               19

// ======================================================
// SD CARD
//
// PIN_SD_DETECT: mechanical card-detect switch in the SD slot.
// Active-LOW: card inserted = LOW, card absent = HIGH.
// Circuit: GPIO → 10kΩ pull-up to 3.3V (on PCB) → switch → GND.
// Configure as GPIO_IN with internal pull-up DISABLED (pull-up is external).
// Can be used for edge-triggered interrupt on card insert/remove.
// ======================================================

#define PIN_SD_CARD_DETECT   8

// ======================================================
// FUTURE USE / HARDWARE ALLOCATIONS ON PCB (not yet implemented in firmware)
// ======================================================
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

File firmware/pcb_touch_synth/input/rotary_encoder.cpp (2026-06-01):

#include <stdio.h>
#include <stdint.h>

#include "pico/stdlib.h"
#include "hardware/gpio.h"
#include "hardware/sync.h"

#include "rotary_encoder.h"
#include "../config/board_config.h"

static volatile int32_t encoder_delta = 0;
static volatile uint8_t last_encoder_state = 0;

static uint8_t read_encoder_state()
{
    uint8_t a = gpio_get(PIN_AUDIO_VOL_A) ? 1 : 0;
    uint8_t b = gpio_get(PIN_AUDIO_VOL_B) ? 1 : 0;

    return (a << 1) | b;
}

static void encoder_gpio_callback(uint gpio, uint32_t events)
{
    (void)gpio;
    (void)events;

    uint8_t current_state = read_encoder_state();

    uint8_t transition = (last_encoder_state << 2) | current_state;

    // Quadrature state table.
    // These are valid one-step transitions.
    switch (transition) {
        case 0b0001:
        case 0b0111:
        case 0b1110:
        case 0b1000:
            encoder_delta++;
            break;

        case 0b0010:
        case 0b1011:
        case 0b1101:
        case 0b0100:
            encoder_delta--;
            break;

        default:
            // No movement or invalid bounce transition.
            break;
    }

    last_encoder_state = current_state;
}

bool rotary_encoder_init()
{
    printf("Initializing rotary encoder...\n");

    gpio_init(PIN_AUDIO_VOL_A);
    gpio_set_dir(PIN_AUDIO_VOL_A, GPIO_IN);
    gpio_disable_pulls(PIN_AUDIO_VOL_A);     // Using external pull-up resistor

    gpio_init(PIN_AUDIO_VOL_B);
    gpio_set_dir(PIN_AUDIO_VOL_B, GPIO_IN);
    gpio_disable_pulls(PIN_AUDIO_VOL_B);     // Using external pull-up resistor

    last_encoder_state = read_encoder_state();
    encoder_delta = 0;

    gpio_set_irq_enabled_with_callback(
        PIN_AUDIO_VOL_A,
        GPIO_IRQ_EDGE_RISE | GPIO_IRQ_EDGE_FALL,
        true,
        &encoder_gpio_callback
    );

    gpio_set_irq_enabled(
        PIN_AUDIO_VOL_B,
        GPIO_IRQ_EDGE_RISE | GPIO_IRQ_EDGE_FALL,
        true
    );

    printf("Rotary encoder initialized. Initial state=%u\n", last_encoder_state);

    return true;
}

int32_t rotary_encoder_get_delta()
{
    int32_t delta;

    uint32_t interrupts = save_and_disable_interrupts();
    delta = encoder_delta;
    encoder_delta = 0;
    restore_interrupts(interrupts);

    return delta;
}

void rotary_encoder_clear_delta()
{
    uint32_t interrupts = save_and_disable_interrupts();
    encoder_delta = 0;
    restore_interrupts(interrupts);
}

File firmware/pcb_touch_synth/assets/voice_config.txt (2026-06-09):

# PCB Piano voice_config.txt
#
# This file serves two roles:
#   1. FLASH FALLBACK — compiled into firmware via CMake (assets/voice_config.txt).
#      Loaded when no SD card is present. Only OSCILLATOR voices produce sound
#      in flash-only mode; WAVETABLE and PLAYBACK entries are parsed but silent
#      because no sample files are available without an SD card.
#
#   2. SD CARD TEMPLATE — copy to /voices/voices.cfg on a FAT32-formatted SD card
#      to customise voices. All three voice types work from SD card.
#
# To update the flash fallback: edit this file and re-flash firmware (hold
# BOOTSEL on power-up, then drag the new .uf2 file to the USB drive).
#
# Lines beginning with # are comments. Blank lines are ignored.
#
# ======================================================
# VOICE FORMATS
# ======================================================
#
#   voice <index> oscillator <waveform> [osc2 W cents] [pitch D ms] [adsr A D S R] [name N]
#   voice <index> wavetable  <filename>                               [adsr A D S R] [name N]
#   voice <index> playback   [filename]                               [adsr A D S R] [name N]
#
#   sample <voice_index> <note_index> <filename>
#
# KEY OVERRIDE FORMAT:
#   key <voice_index> <key_index> oscillator <waveform> [options...] [name N]
#
#   Assigns an independent sound to one keyboard key (0–19) within a voice.
#   When that key is pressed, the key's own oscillator, ADSR, pitch envelope,
#   and fixed frequency are used instead of the voice defaults.  All other
#   keys continue to use the voice definition unchanged.  This is the primary
#   mechanism for building drum kits: each key becomes a different drum
#   instrument with its own waveform, tuning, and envelope.
#
#   Key override options (keyword-scanned, order-independent except name last):
#     osc2 <waveform> <detune_cents>
#     pitch <depth> <ms>
#     adsr <attack_ms> <decay_ms> <sustain_0.0-1.0> <release_ms>
#     name <words to end of line>
#
#   Fixed frequency (omit entirely for melodic use — plays at MIDI pitch):
#     note C4   — note name: A–G, optional # or b, octave -1..9
#                 Standard MIDI: C4=261Hz  A4=440Hz  C2=65Hz  C1=33Hz
#     midi 60   — MIDI note number 0–127  (C4=60  A4=69  C2=36)
#     freq 55.0 — raw Hz for those who reference drum machine specs
#
#   TYPICAL DRUM FREQUENCIES:
#     Kick body : C2  (65Hz) to E2 ( 82Hz)  — midi 36–40
#     Bass tom  : E2  (82Hz) to B2 (123Hz)  — midi 40–47
#     Mid tom   : B2 (123Hz) to G3 (196Hz)  — midi 47–55
#     High tom  : G3 (196Hz) to D4 (294Hz)  — midi 55–62
#     Snare body: F#3(185Hz) to B3 (247Hz)  — midi 54–59
#
#   MEMORY BUDGET FOR KEY OVERRIDES:
#   Each key override uses ~32 bytes of heap, allocated only when configured.
#   The RP2040 has 264 KB SRAM; with firmware, stack, and audio buffers using
#   roughly 100 KB, approximately 125 KB of heap is available for voice data.
#   Safe maximum across all banks: ~3,900 key overrides total.
#   A full configuration (16 banks × 16 voices × 12 keys avg) uses ~98 KB —
#   within budget with room to spare.  SampleSlot entries use ~66 bytes each.
#
#   sample <voice_index> <note_index> <filename>
#
# OSCILLATOR waveforms : sine  square  saw  triangle  noise
#   noise = white noise (xorshift32 PRNG); has no pitch — each sample is
#           an independent random value. Use for snare body, hi-hat, clap.
#
# osc2 — optional second oscillator for dual-oscillator voices.
#   osc2 <waveform> <detune_cents>
#
#   WHAT IS A CENT?
#   A cent is a unit of musical pitch. There are 100 cents between any two
#   adjacent keys on a piano (including black keys), and 1200 cents in one
#   full octave. Familiar piano-key intervals expressed in cents:
#
#     100  cents = 1 piano key  (e.g. C  to C#)
#     200  cents = 2 piano keys (e.g. C  to D )  — whole step
#     700  cents = 7 piano keys (e.g. C  to G )  — perfect fifth
#     1200 cents = 12 piano keys (one full octave, e.g. C4 to C5)
#     1900 cents = 19 piano keys (octave + fifth, e.g. C4 to G5)
#
#   SMALL DETUNE VALUES (5–20 cents) are less than one piano key apart.
#   At that range you do not hear two separate pitches — instead the two
#   oscillators slowly drift in and out of phase with each other, creating
#   a chorus / beating effect that makes the sound feel thick and wide.
#   The wider the detune, the faster the beating.
#     5–7  cents : subtle shimmer
#     12   cents : slow, lush beating (classic "Jump Lead" thickness)
#     20   cents : noticeable movement, dense wall-of-sound character
#
#   LARGE DETUNE VALUES add a harmonic layer at a musical interval:
#     +1200 = one octave above  — upper register layer (organ)
#     -1200 = one octave below  — sub-bass layer
#     +700  = perfect fifth above
#     +1900 = perfect 12th (octave + fifth) — dominant bell partial
#
#   detune_cents range: −2400..+2400 (signed integer)
#   The two oscillators are averaged so peak level stays constant.
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

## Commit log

2026-05-11 Development Phase - Initial github push.
    Initial github push. Still in development. Nothing finalized. Schematic 95% complete. Starting PCB organization and layout; only piano keys are final size and placement.
2026-05-12 PCB work - v0.1
    PCB Work v0.1. Moved audio Amp and AGND to top right corner.
    [PCB Piano v1.0.kicad_pcb, PCB Piano v1.0.kicad_sch, audio.kicad_sch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]
2026-05-14 Development Phase Update
    PCB layout refined more, still not complete. Trying to start a separate v1.1 PCB file to explore a 4-layer PCB.
    [PCB Piano v1.0.kicad_pcb, PCB Piano v1.0.kicad_sch, PCB Piano v1.1.kicad_pcb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]
2026-05-15 Development Step
    More PCB Layout work completed. Added MEMS microphone. Moved around debug connector signals. Changed Speaker to just a cut out (will 3D print a grille to go into cutout.)
    [PCB Piano v1.0.kicad_pcb, PCB Piano v1.0.kicad_sch, PCB Piano v1.1.kicad_pcb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]
2026-05-18 Development Phase - PCB Complete - ERC/DRC in progress
    Development commit. PBC layout complete. ERC/DRC checks in progress. Swapped some connectors for JST connectors with Adafruit-style polarization.
    [PCB Piano v1.1.kicad_pcb, PCB Piano v1.1.kicad_sch, audio.kicad_sch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]
2026-06-01 Firmware architecture complete - PCB revision with new charger.
    Firmware Architecture Complete
    - Added MP2724 charger driver
    - Added TLV320DAC3100 driver
    - Added MTCH2120 touch driver
    - Added PCA9685 driver
    - Added DotStar driver
    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
    [10067099-200lf.stp, B2B-PH-SM4-TB.STEP, B3B-PH-SM4-TB.STEP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]
2026-06-01 I2C address file tweak.
    Just reorganizing I2C address file.
2026-06-09 PCB Finalized and Ordered. Firmware near completion.
    PCB Finalized and Ordered. Final revisions included fixing bugs on some peripheral chips. Also added an RTC circuit after realizing the SD card could benefit from adding file timestamps.
    Firmware near completion. Still need to finalize some SD card operations. Synth audio core is finished and all the board peripheral chip drivers were completed.
    [Debug Breakout.kicad_pcb, Debug Breakout.kicad_sch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]
